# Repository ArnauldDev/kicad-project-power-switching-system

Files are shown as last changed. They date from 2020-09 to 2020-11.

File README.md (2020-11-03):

# Power switching system

Realization of a power supply board with four switches for switching between several power sources.

## Check list

- [x] Analysis of the specifications
- [x] Choice of components and case
- [x] Order components
- [x] Validation of the schematic
- [x] Definition of the PCB outline from the internal dimensions of the case
- [x] Validate component placement and lock footprints
- [x] Routing validation
- [x] Screen printing validation
- [x] Generating design files
- [x] Assembly of components on the PCB
- [x] Functional test of the electronic board and validation of the specifications
- [x] Integration of the electronic card in the case
- [x] Final test and document review
- [ ] Device delivery

---

## Tools used

### KiCad

[KiCad EDA - Schematic Capture & PCB Design Software](https://kicad-pcb.org/), version: 5.1.7

Open source EDA / electronics CAD software for Windows, macOS and Linux.

### FreeCAD - 3D parametric modeler

[FreeCAD](https://www.freecadweb.org/?lang=fr), version: 0.18.4

## Electrical diagram

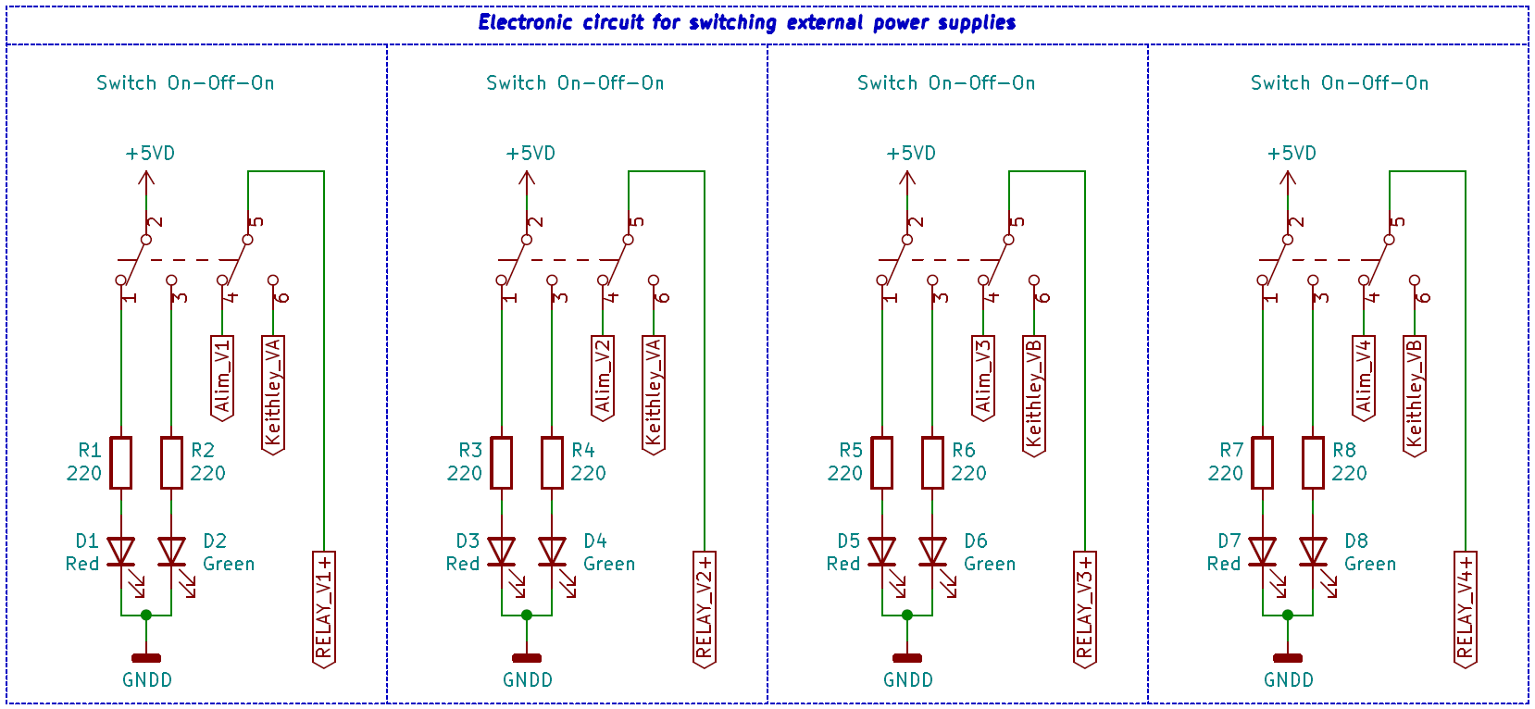
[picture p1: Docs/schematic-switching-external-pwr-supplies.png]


---

## Integration into the housing

[Hammond 1599HGYBAT](https://www.hammfg.com/part/1599HGYBAT)

Enclosure - plastic, size: 220 mm x 110 mm x 44 mm (L x W x H)

## PCB outline, size: 213,00 mm x 96,60 mm (L x W), from FreeCAD

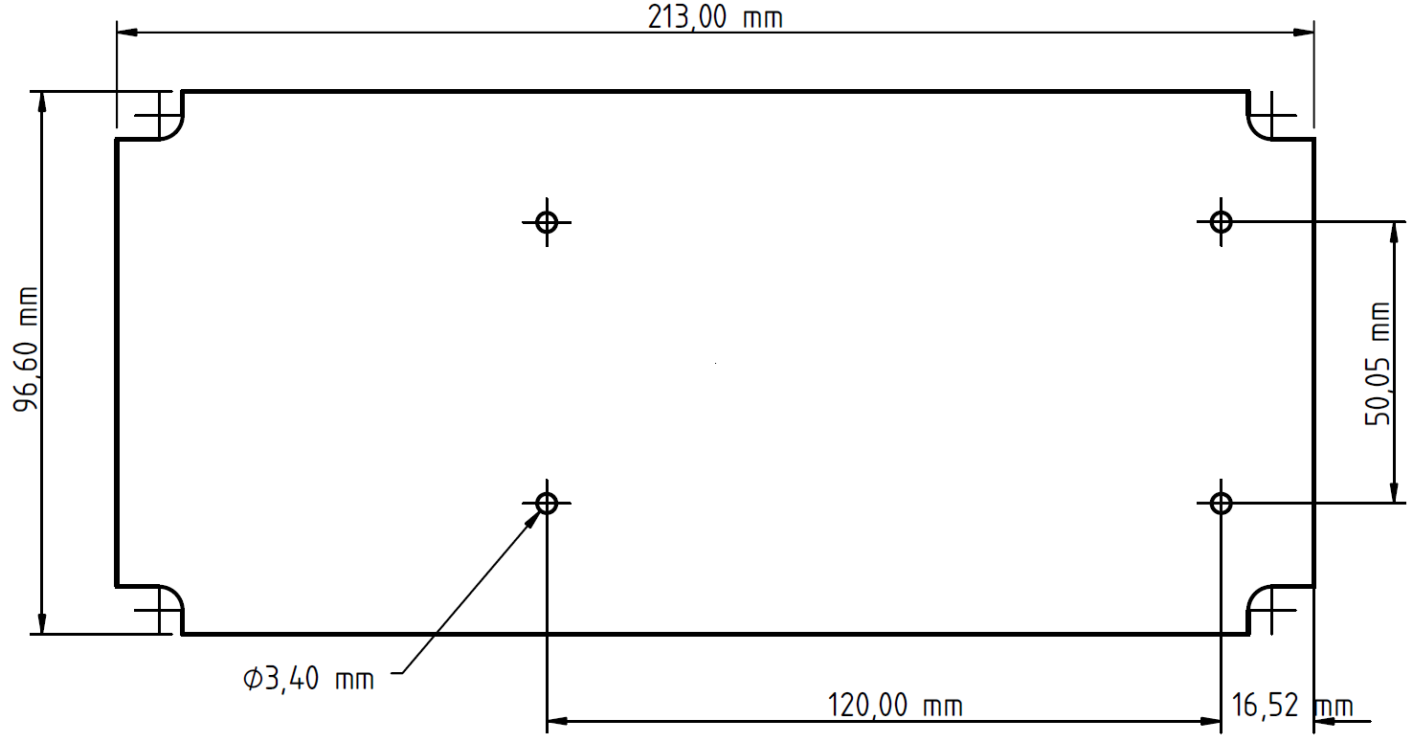
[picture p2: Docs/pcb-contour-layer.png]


## Component placement and silk screen

| Placement | Silk screen |
| :---: | :---: |
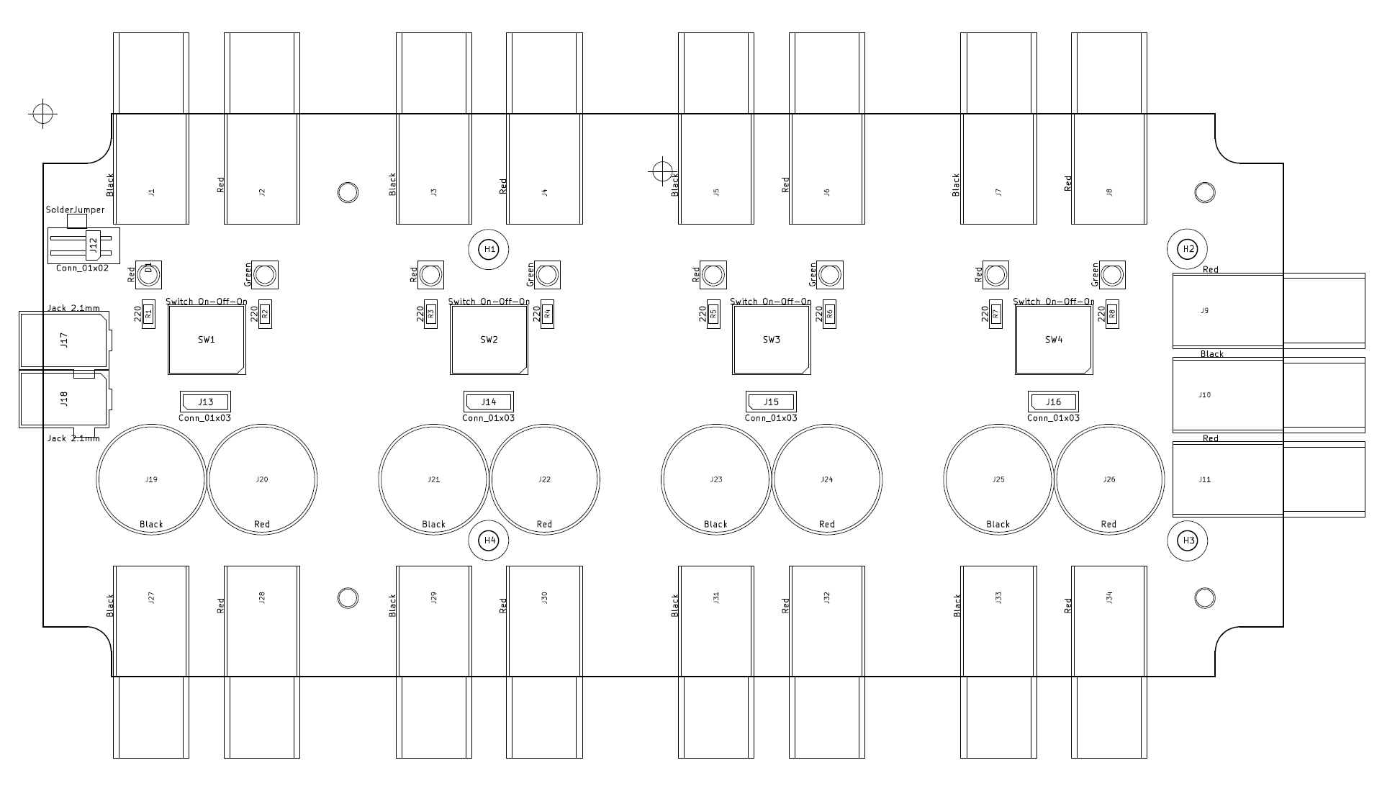
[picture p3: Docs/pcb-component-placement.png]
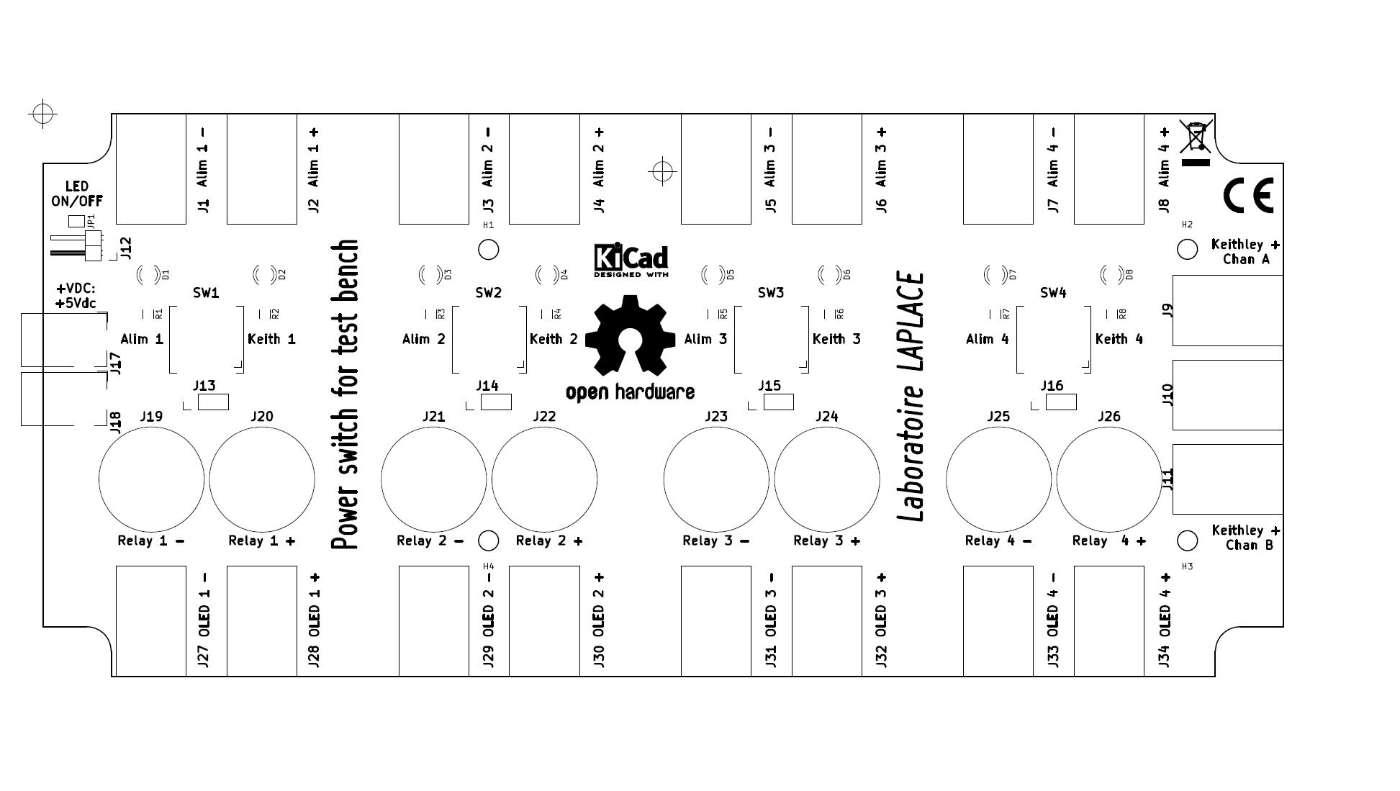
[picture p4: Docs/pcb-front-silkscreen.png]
|  |  |
| F.Mask + Edge.Cuts + F.CrtYd + F.Fab | F.SilkS + Edge.Cuts |

|                      Placement and Silk screen                      |
| :-----------------------------------------------------------------: |
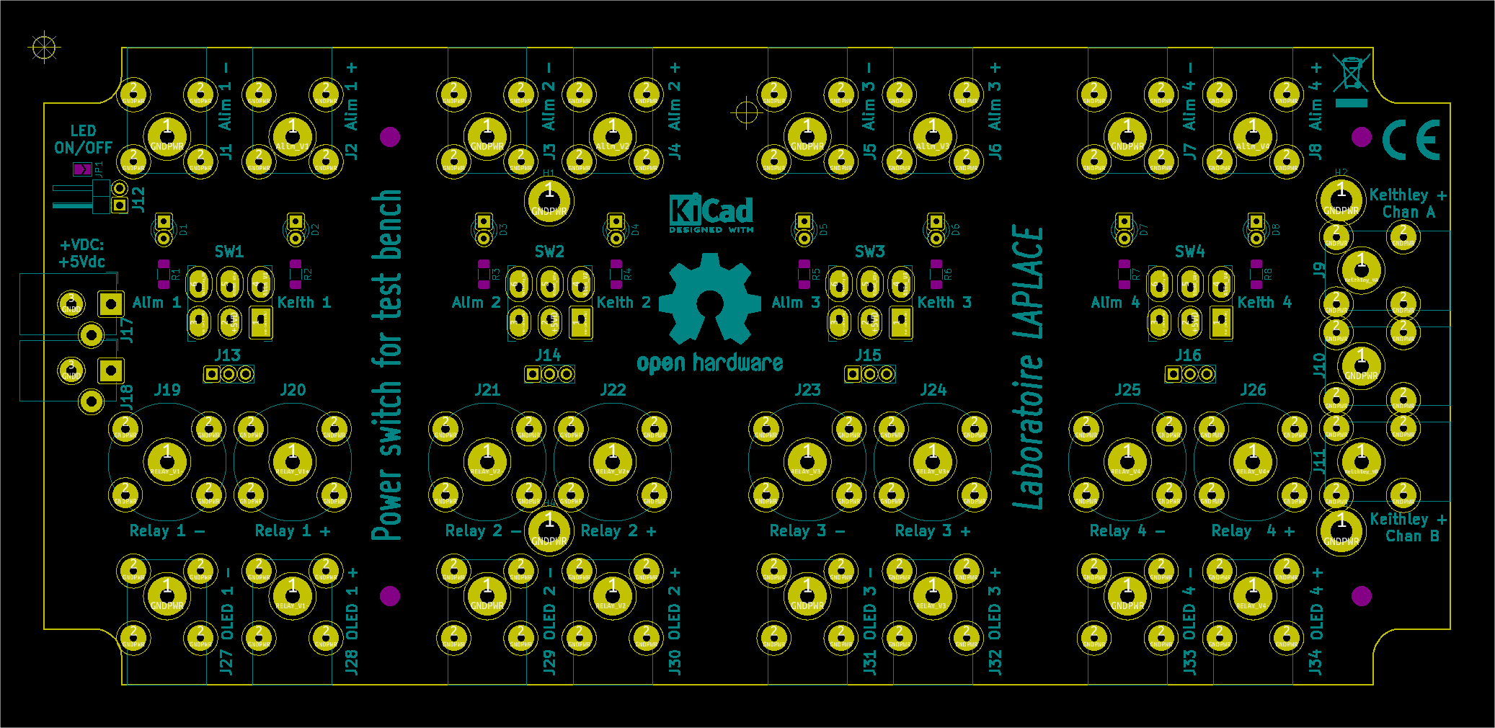
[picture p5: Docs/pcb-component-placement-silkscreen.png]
|  |
|           F.SilkS + F.Mask + Edge.Cuts + F.CrtYd + F.Fab            |

<!--
### Component placement - Component layout

<img src="Docs/pcb-component-placement.png" width="800">

F.Mask + Edge.Cuts + F.CrtYd + F.Fab

### Silk screen

<img src="Docs/pcb-front-silkscreen.png" width="800">

F.SilkS + Edge.Cuts
-->

## Top - Front Copper layer

<!-- ![pcb-front-copper-layer](Docs/pcb-front-copper-layer.png) -->
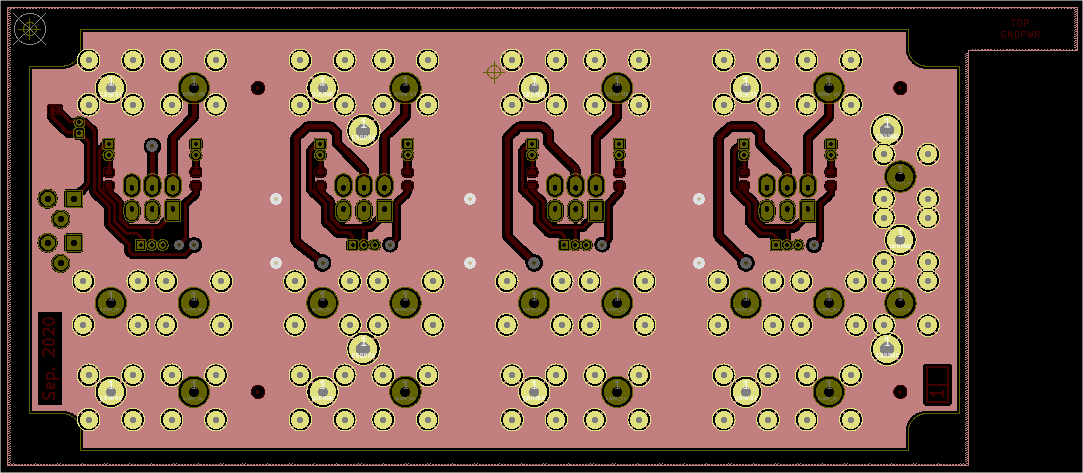
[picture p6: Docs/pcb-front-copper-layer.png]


## Bottom - Back Copper layer

<!-- ![pcb-back-copper-layer](Docs/pcb-back-copper-layer.png) -->
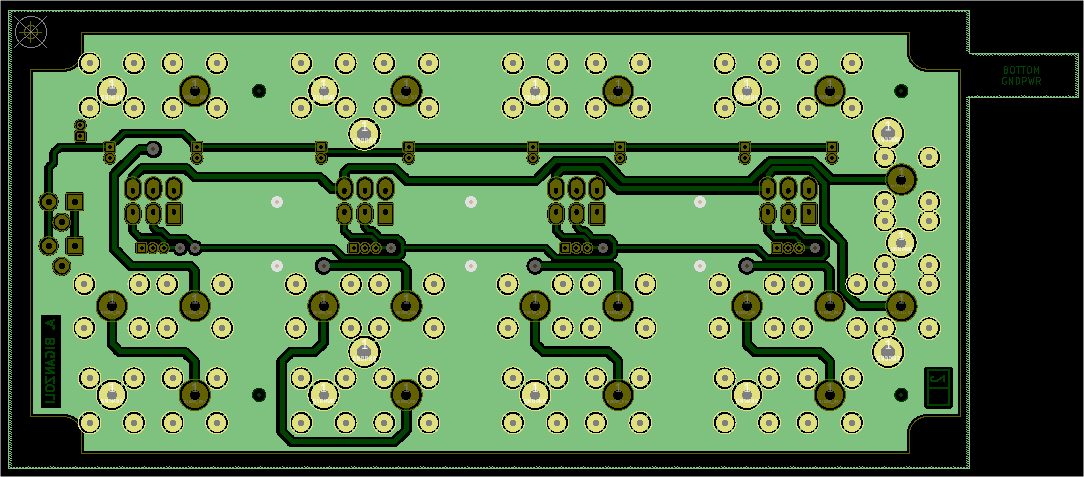
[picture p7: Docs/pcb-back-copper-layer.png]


<!-- ## Component layout

pcb-component-placement.pdf
 -->

## 3D rendering

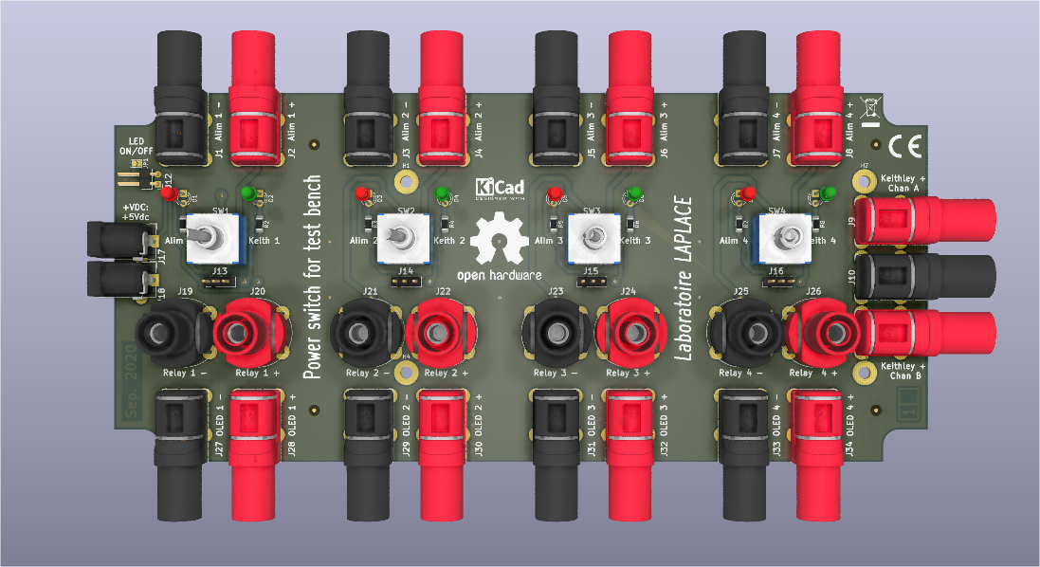
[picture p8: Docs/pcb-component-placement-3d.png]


## Integration of the electronic card in the case with the [FreeCAD](https://www.freecadweb.org) software

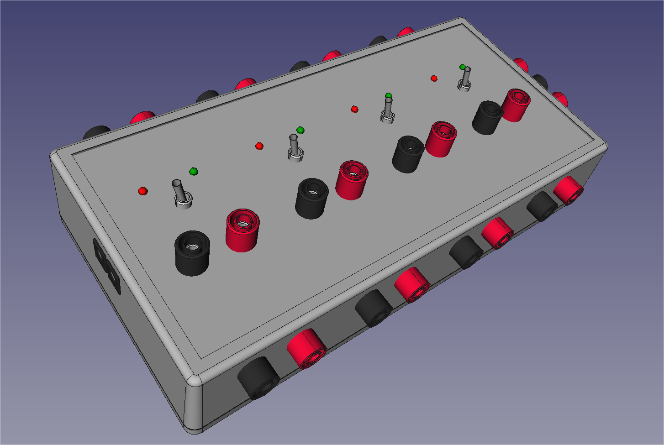
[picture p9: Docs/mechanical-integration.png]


## Sectional view

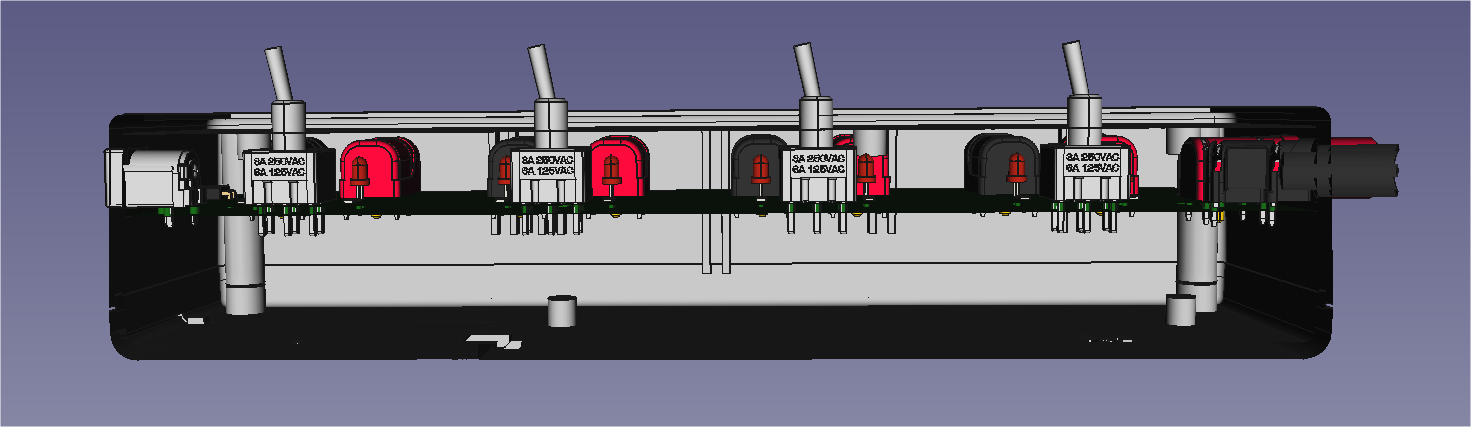
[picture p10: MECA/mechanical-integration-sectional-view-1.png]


## View of final STEP file for CNC

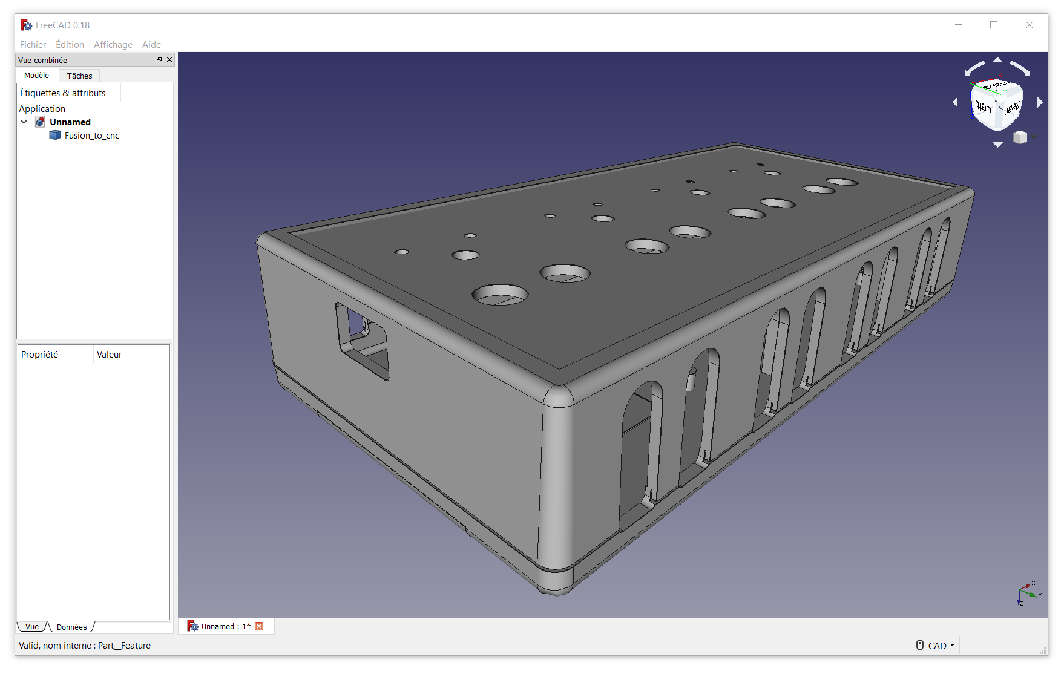
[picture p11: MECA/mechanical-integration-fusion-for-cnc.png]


---

## [CHANGELOG](CHANGELOG.md)

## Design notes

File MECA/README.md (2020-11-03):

# Boîtier Hammond en ABS, 220 x 110 x 44mm, Gris IP54

Code commande RS [514-1897](https://fr.rs-online.com/web/p/boitiers-pour-usage-general/5141897/)

Référence fabricant [1599HGYBAT](https://www.hammfg.com/part/1599HGYBAT)

Marque Hammond

Fixer les LED entre 16 et **18** mm du haut par rapport au plan Top du PCB.

Prévoir colonnette ou entretoise pour réhausser la carte de :

* 18.52 mm depuis l'extrémité supérieur des colonnettes du boitier, diamètre extérieur 5.5 mm
* 23.28 mm du font du boitier au dessous du PCB (for spacer)

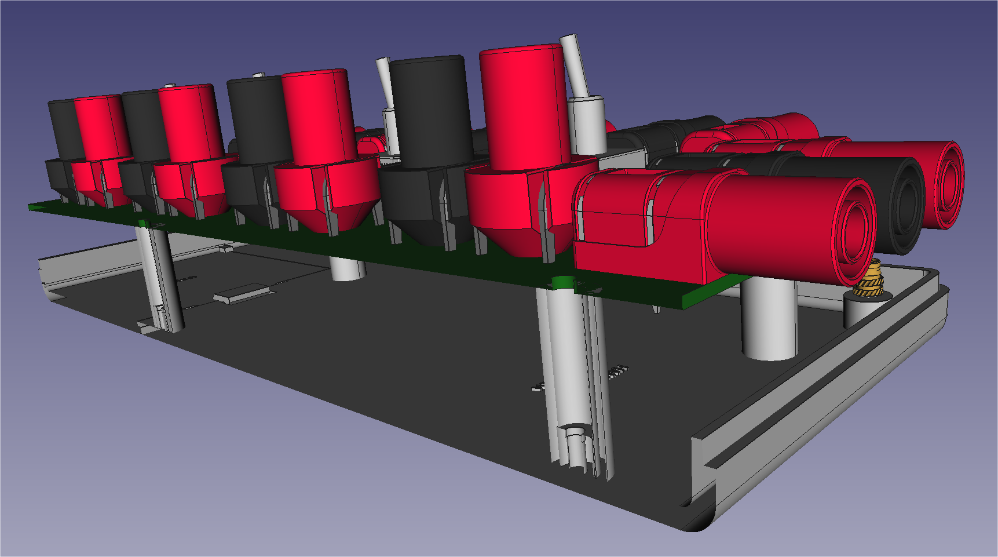
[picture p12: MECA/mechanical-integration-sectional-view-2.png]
Spacer H1:H4


## FreeCAD - 3D parametric modeler

[FreeCAD](https://www.freecadweb.org/?lang=fr), version: 0.18.4

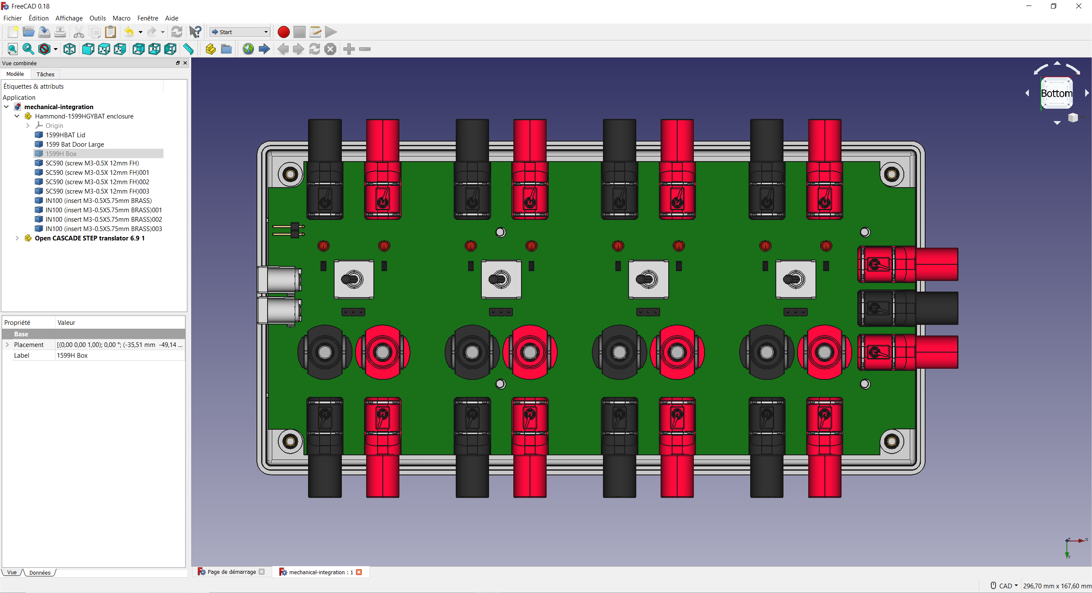
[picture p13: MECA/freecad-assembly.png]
FreeCAD Assembly


## Visualization of the machining of the housing

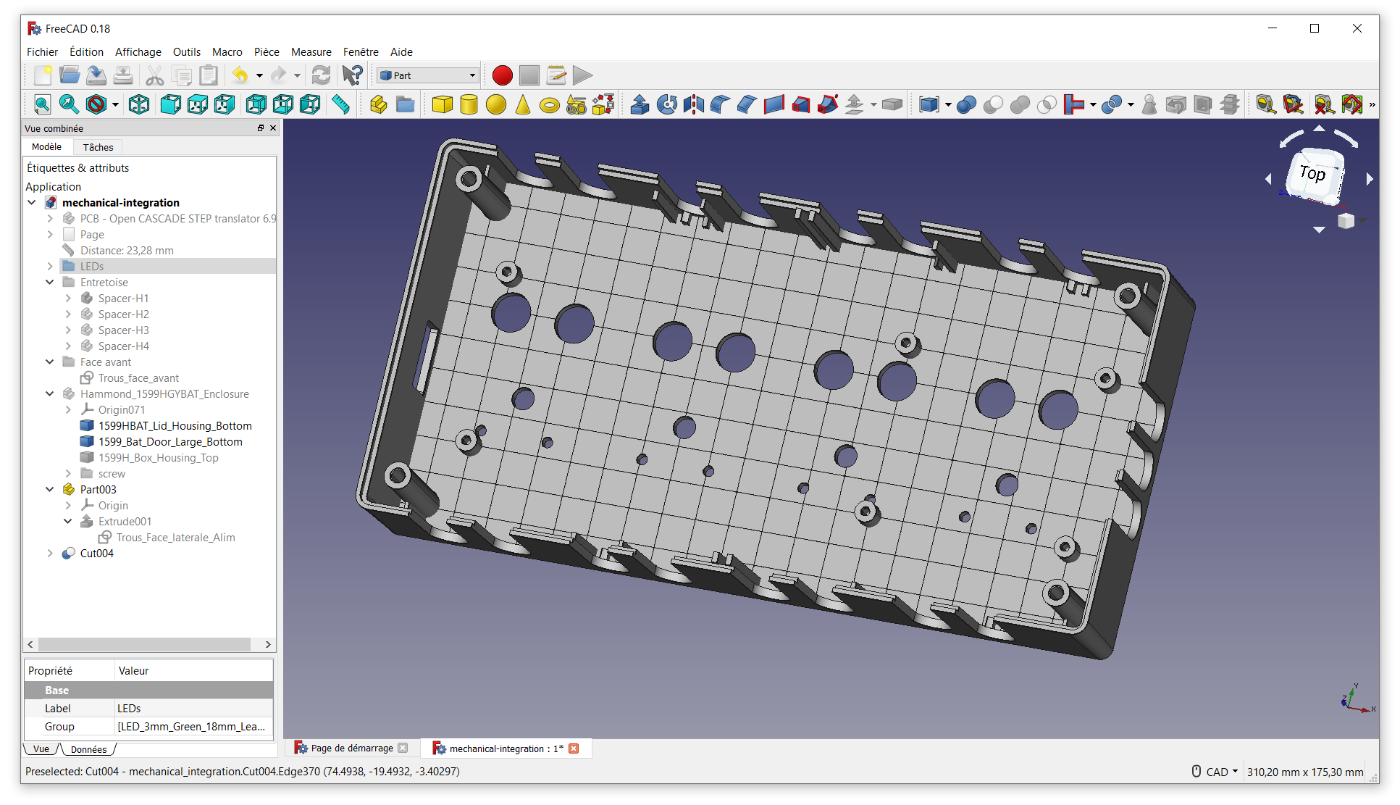
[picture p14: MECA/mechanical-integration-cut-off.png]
Machining of the housing


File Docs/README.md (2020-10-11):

# Project documents

## About the use of KiCad

    Application: KiCad
    Version: (5.1.7)-1, release build
    Libraries:
        wxWidgets 3.0.5
        libcurl/7.71.0 OpenSSL/1.1.1g (Schannel) zlib/1.2.11 brotli/1.0.7 libidn2/2.3.0 libpsl/0.21.0 (+libidn2/2.3.0) libssh2/1.9.0 nghttp2/1.41.0
    Platform: Windows 8 (build 9200), 64-bit edition, 64 bit, Little endian, wxMSW
    Build Info:
        wxWidgets: 3.0.5 (wchar_t,wx containers,compatible with 2.8)
        Boost: 1.73.0
        OpenCASCADE Community Edition: 6.9.1
        Curl: 7.71.0
        Compiler: GCC 10.2.0 with C++ ABI 1014

    Build settings:

        KICAD_SCRIPTING_WXPYTHON=ON
        KICAD_SCRIPTING_WXPYTHON_PHOENIX=OFF
        KICAD_SCRIPTING_ACTION_MENU=ON
        BUILD_GITHUB_PLUGIN=ON
        KICAD_USE_OCE=ON
        KICAD_USE_OCC=OFF
        KICAD_SPICE=ON

### Local library

    .
    └── kicad-project-power-switching-system
        ├── kicad_local_lib
        └── kicad_local_mod
            └── Button_Switch_THT.pretty (Local_Button_Switch_THT)
            └── Connector_Banana.pretty (Local_Connector_Banana)
            └── Connector_BarrelJack.pretty (Local_Connector_BarrelJack)
            └── Layer_ID.pretty
            └── LED_THT.pretty
            └── packages3d
                └── Button_Switch_THT.3dshapes
                └── Connector_Banana.3dshapes
                └── Connector_BarrelJack.3dshapes
                └── LED_THT.3dshapes

### Library management in KiCad version 5

[KiCad Library Convention](https://kicad-pcb.org/libraries/klc/)

### Additional fields in Symbol Properties

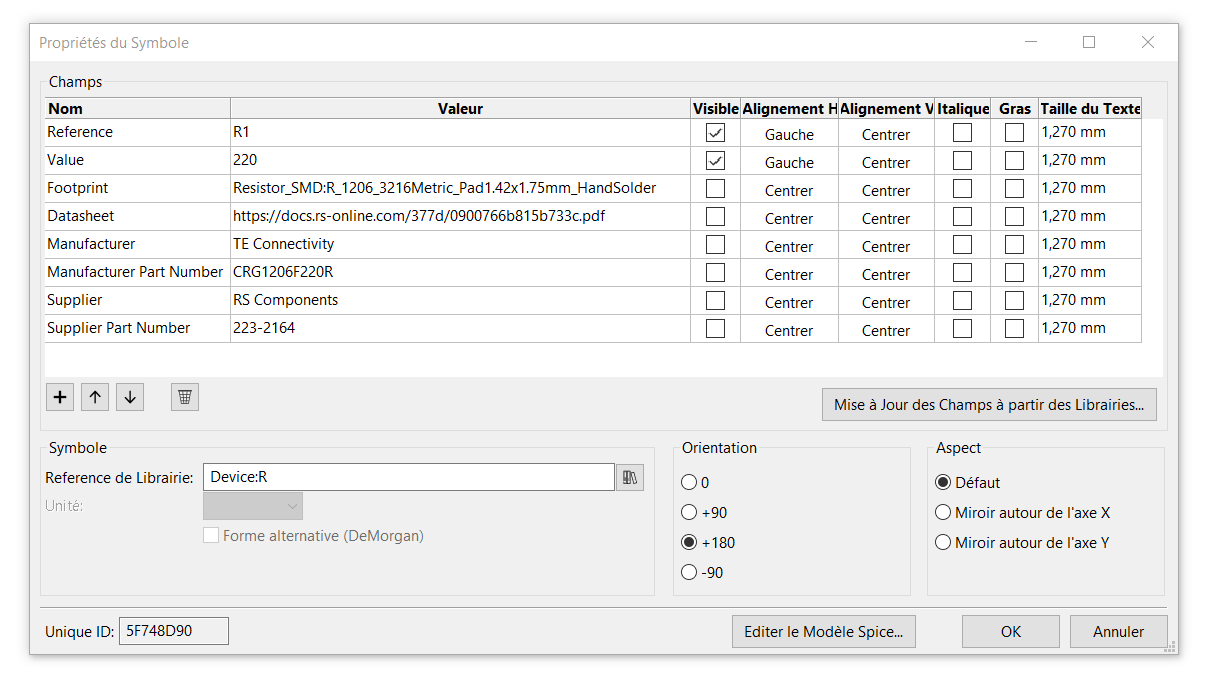
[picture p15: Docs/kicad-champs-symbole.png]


---

## About the use of FreeCAD

https://www.freecadweb.org/downloads.php

    OS: Windows 10
    Word size of OS: 64-bit
    Word size of FreeCAD: 64-bit
    Version: 0.18.4 (GitTag)
    Build type: Release
    Branch: releases/FreeCAD-0-18
    Hash: 980bf9060e28555fecd9e3462f68ca74007b70f8
    Python version: 3.6.6
    Qt version: 5.6.2
    Coin version: 4.0.0a
    OCC version: 7.3.0
    Locale: French/France (fr_FR)

---

## Open Source Hardware Association

<!-- ![oshw-logo](oshw-logo-200-px.png) -->
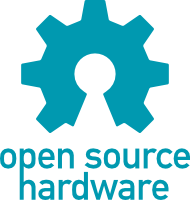
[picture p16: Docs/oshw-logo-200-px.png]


https://www.oshwa.org/

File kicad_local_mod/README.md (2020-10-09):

# kicad-local_mod

Project footprint

## Change lists

### SW_TME_1MD3T1B1M1QE_DPDT_Straight.kicad_mod

Edit inter footprint

oblong hole : 0.9 x 1.3 mm

--> 1.0 x 1.4 mm

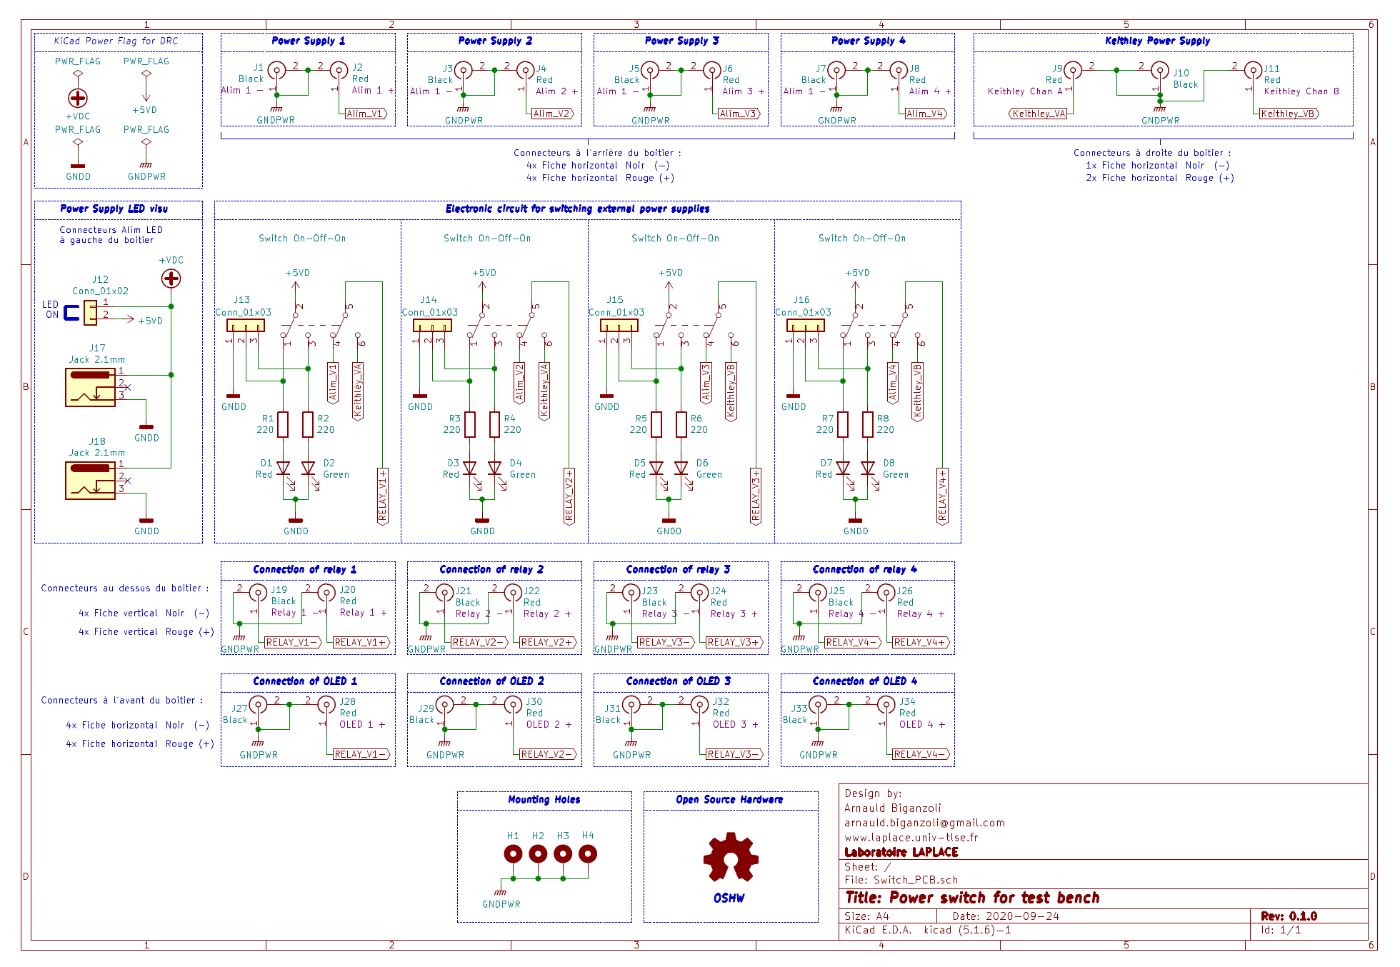
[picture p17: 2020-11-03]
Docs/schematic-switch-alim-v0-1-0.png

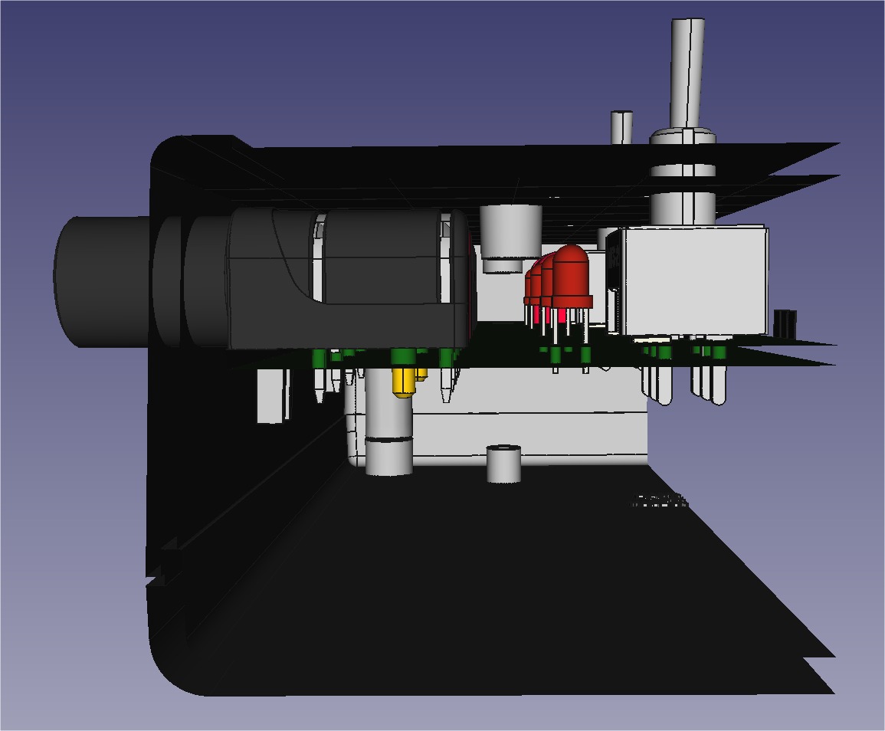
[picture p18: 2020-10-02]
MECA/mechanical-integration-sectional-view-3.png

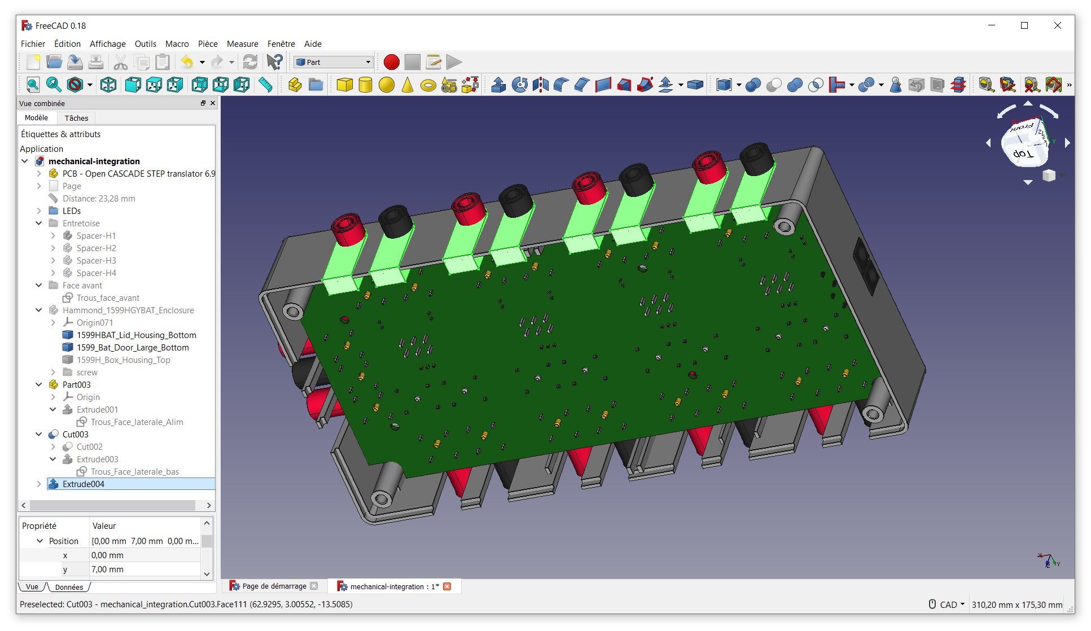
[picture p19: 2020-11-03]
MECA/mechanical-integration-add-part-for-subtraction.png

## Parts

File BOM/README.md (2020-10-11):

# Bill Of Materials (BOM), public prices as of september 2020

 | Description                                                                     | Supplier         | Supplier Part Number    | Quantity | By multiple of    | Unit price | Row value |
 | :------------------------------------------------------------------------------ | :--------------- | :---------------------: | :------: | ----------------- | ---------: | --------: |
 | Boîtier Hammond en ABS, 220 x 110 x 44mm, Gris IP54                             | RS Components    | [514-1897][url_5141897] |    1     | unit              |    12,16 € |   12,16 € |
 | Alimentation enfichable 5V c.c., 1A, 5W                                         | RS Components    | [121-7115][url_1217115] |    1     | unit              |     6,67 € |    6,67 € |
 | Connecteur Jack RS PRO Double c.c. Femelle 2,1 mm, 2,5 mm, Montage sur CI       | RS Components    | [805-1699][url_8051699] |    2     | in multiples of 5 |    1,282 € |    6,41 € |
 | Alimentation enfichable 5V c.c., 1A, 5W                                         | RS Components    | [121-7115][url_1217115] |    1     | unit              |    6,003 € |    6,00 € |
 | LED Rouge, Traversant, 3 mm (T-1), 2 V                                          | RS Components    | [228-5916][url_2285916] |    4     | in multiples of 5 |    0,126 € |    0,63 € |
 | LED Vert, Traversant, 3 mm (T-1), 2,2 V                                         | RS Components    | [228-5944][url_2285944] |    4     | in multiples of 5 |    0,126 € |    0,63 € |
 | Fiche banane Staubli Noir Femelle 24A 1 kV, 600 V (vertical)                    | RS Components    | [122-9670][url_1229670] |    4     | unit              |    6,138 € |  24,552 € |
 | Fiche banane Staubli Rouge Femelle 24A 1 kV, 600 V (vertical)                   | RS Components    | [122-9671][url_1229671] |    4     | unit              |    6,138 € |  24,552 € |
 | Fiche banane Schutzinger Noir Embase 24A 1kV (horizontal)                       | RS Components    | [144-1451][url_1441451] |    9     | unit              |    5,238 € |  47,142 € |
 | Fiche banane Schutzinger Rouge Embase 24A 1kV (horizontal)                      | RS Components    | [144-1450][url_1441450] |    10    | unit              |    5,238 € |    52,4 € |
 | Interrupteur à levier RS PRO, On-Off-On, 2RT, 5 A @ 28 V c.c.                   | RS Components    | [401-692][url_0401692]  |    4     | unit              |    2,484 € |   9,936 € |
 | _______________________________________________________________________________ | ________________ | _______________________ | ________ | _________________ | __________ | _________ |
 |                                                                                 |                  |                         |          |                   |      TOTAL |  191,08 € |

[url_5141897]: https://fr.rs-online.com/web/p/boitiers-pour-usage-general/5141897
[url_1217115]: https://fr.rs-online.com/web/p/adaptateurs-ac-dc/1217115/
[url_8051699]: https://fr.rs-online.com/web/p/fiches-et-prises-jack/8051699/
[url_1217115]: https://fr.rs-online.com/web/p/adaptateurs-ac-dc/1217115/
[url_2285916]: https://fr.rs-online.com/web/p/led/2285916/
[url_2285944]: https://fr.rs-online.com/web/p/led/2285944/
[url_1229670]: https://fr.rs-online.com/web/p/fiches-bananes/1229670/
[url_1229671]: https://fr.rs-online.com/web/p/fiches-bananes/1229671/
[url_1441451]: https://fr.rs-online.com/web/p/fiches-bananes/1441451/
[url_1441450]: https://fr.rs-online.com/web/p/fiches-bananes/1441450/
[url_0401692]: https://fr.rs-online.com/web/p/interrupteurs-a-levier/0401692/

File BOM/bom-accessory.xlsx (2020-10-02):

Reference | Quantity | Value | Footprint | Datasheet | Description | Manufacturer | Manufacturer Part Number | Supplier | Supplier Part Number
 | 1 |  |  |  | Boîtier Hammond en ABS, 220 x 110 x 44mm, Gris IP54 | Hammond | 1599HGYBAT | RS Components | 514-1897

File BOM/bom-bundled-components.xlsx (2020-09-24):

Reference | Quantity | Value | Footprint | Datasheet | Description | Manufacturer | Manufacturer Part Number | Supplier | Supplier Part Number
D1 D7 D5 D3 | 4 | Red | LED_THT:LED_D3.0mm | https://docs.rs-online.com/5919/0900766b813955e6.pdf | LED Alim 1 | Kingbright | L-934ID | RS Components | 228-5916
D8 D6 D4 D2 | 4 | Green | LED_THT:LED_D3.0mm | https://docs.rs-online.com/c1ec/0900766b813955e9.pdf | LED Keith VB2 | Kingbright | L-934GD | RS Components | 228-5944
H1 H2 H3 H4 | 4 | MountingHole_Pad | MountingHole:MountingHole_3.2mm_M3_Pad | ~
J10 J7 J5 J3 J1 J21 J23 J25 J27 | 9 | Black | ArnauldDev_Connector_Banana:SCHUTZINGER_SWEB8094AU-SW_4mm_Horizontal | https://www.schuetzinger.de/files/sweb_8094_au_110520.pdf | GND | Schutzinger | SWEB 8094 Au / SW | RS Components | 144-1451
J12-1 J12-2 | 2 | Jack 2.1mm | ArnauldDev_Connector_BarrelJack:BarrelJack_FC681465P_Pin3_Horizontal | https://www.cliffuk.co.uk/products/dcconnectors/FC681465P.pdf | Alim 5 Vdc | CLIFF | FC681465P (DC-10LP) | RS Components | 805-1699
J13 J15 J17 J19 | 4 | Black | ArnauldDev_Connector_Banana:STAUBLI_66.9032-21_XELA-4_4mm_Vertical | https://ec.staubli.com/AcroFiles/MA/TM_MAH565_(de-en-fr).pdf | Relay 1 - | Staubli | 66.9032-21 | RS Components | 122-9670
J14 J16 J18 J20 | 4 | Red | ArnauldDev_Connector_Banana:STAUBLI_66.9032-21_XELA-4_4mm_Vertical | https://ec.staubli.com/AcroFiles/MA/TM_MAH565_(de-en-fr).pdf | Relay 1 + | Staubli | 66.9032-22 | RS Components | 122-9671
J4 J9 J6 J8 J11 J2 J26 J22 J28 J24 | 10 | Red | ArnauldDev_Connector_Banana:SCHUTZINGER_SWEB8094AU-SW_4mm_Horizontal | https://www.schuetzinger.de/files/sweb_8094_au_110520.pdf | Alim 2 + | Schutzinger | SWEB 8094 Au / RT | RS Components | 144-1450
R8 R7 R6 R5 R4 R3 R2 R1 | 8 | 220 | Resistor_SMD:R_1206_3216Metric_Pad1.42x1.75mm_HandSolder | https://docs.rs-online.com/377d/0900766b815b733c.pdf |  | TE Connectivity | CRG1206F220R | RS Components | 223-2164
SW3 SW4 SW2 SW1 | 4 | Switch On-Off-On | ArnauldDev_Button_Switch_THT:SW_TME_1MD3T1B1M1QE_DPDT_Straight | https://datasheet.octopart.com/401692-RS-Pro-datasheet-110811736.pdf | Switch of Alim 3 | RS PRO / TME | 1MD3T1B1M1QE | RS Components | 401-692

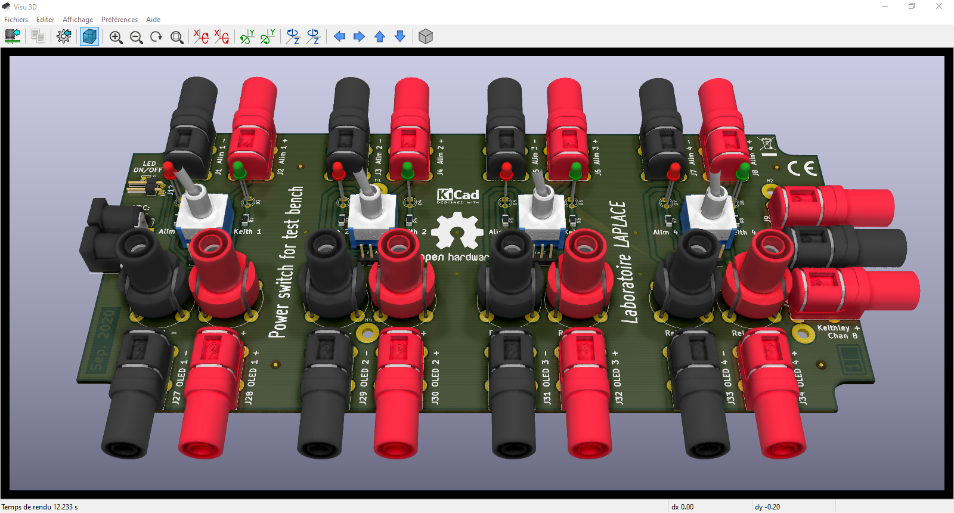
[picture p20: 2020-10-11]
Docs/pcb-component-placement-3d-inc.png

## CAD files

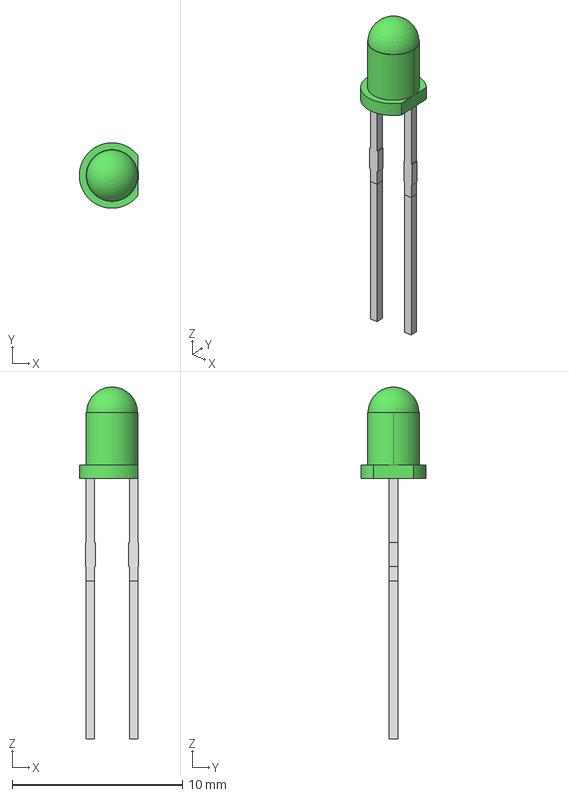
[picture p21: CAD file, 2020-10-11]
MECA/led/led-3mm-green-h18mm.FCStd
3.50 x 3.85 x 20.7 mm
LEDBody
Lead1Body
Lead2Body
LEDHead
Lead1Pcb
Lead2Pcb

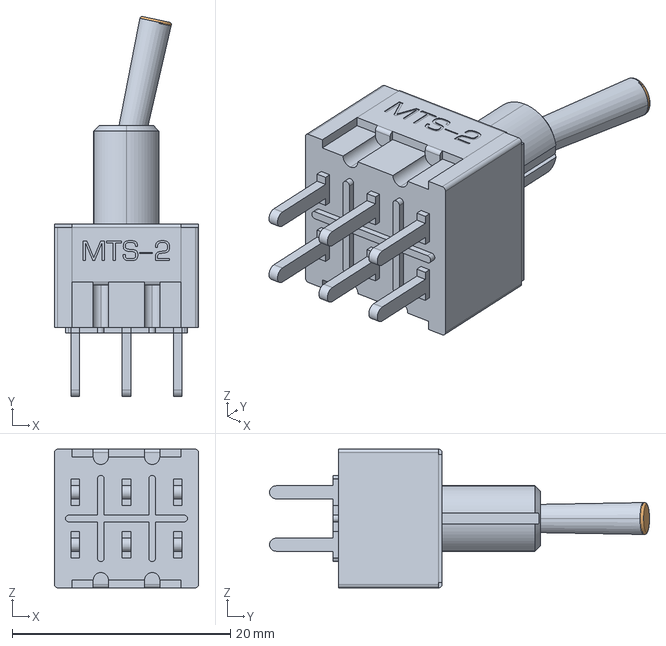
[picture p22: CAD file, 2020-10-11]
MECA/SW_TME_1MD3T1B1M1QE_DPDT_Straight.FCStd
13.2 x 34.8 x 12.7 mm
User Library-MTS-20x-A2

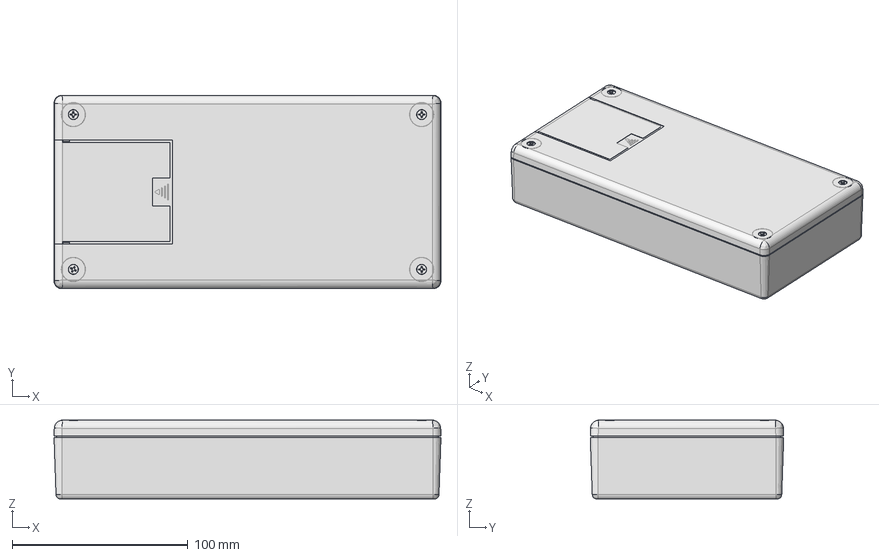
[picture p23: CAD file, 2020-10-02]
MECA/Hammond-1599HGYBAT.step
220.0 x 110.0 x 44.9 mm
1599H Lid
1599 Bat Door Large
1599H Box
SC500 (screw M3-0.5X 10mm FH) x 4
Insert x 4

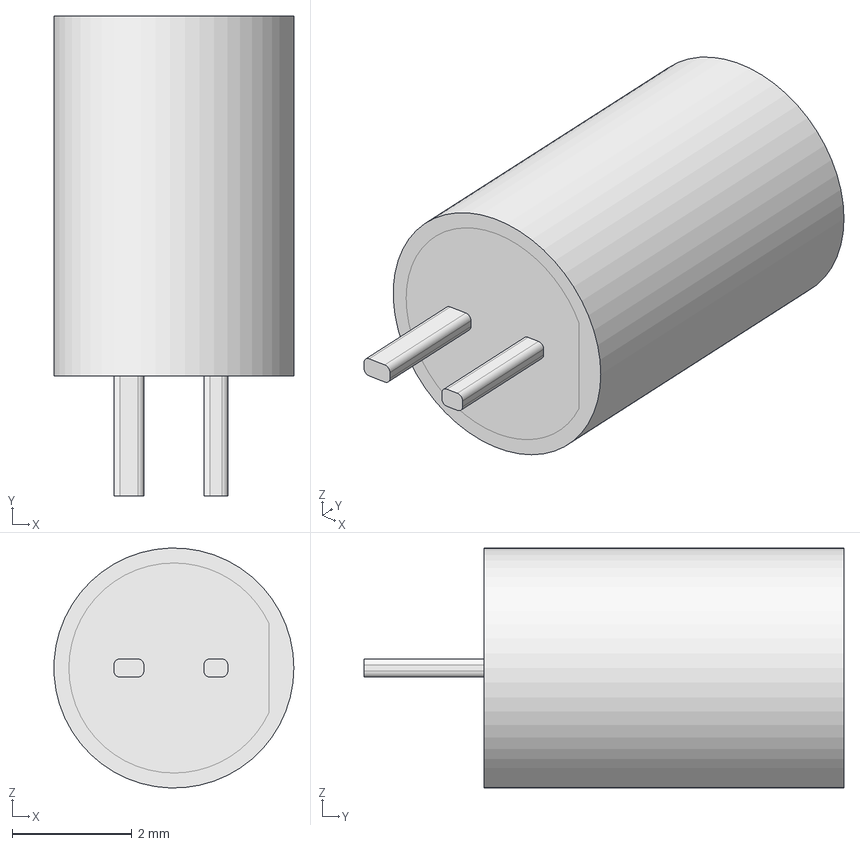
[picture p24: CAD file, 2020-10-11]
MECA/led/led-3mm-green.FCStd
4.00 x 8.00 x 4.00 mm

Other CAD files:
MECA/led/led-3mm-red-h18mm.FCStd
MECA/led/LED_D3.0mm_H18.0mm_Red.step
MECA/led/LED_D3.0mm_H18.0mm_Green.step

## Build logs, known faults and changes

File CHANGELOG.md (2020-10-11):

## 0.1.1 - 2020-10-11

> kicad_local_mod\Connector_Banana.pretty\SCHUTZINGER_SWEB8094AU-RT_4mm_Horizontal_Red.kicad_mod

* Change reference position of an object in FreeCAD, so that it is correctly placed in KiCad

## 0.1.0 - 2020-10-10

* Added: insert layers number on pcb

## 0.0.9 - 2020-10-09

* Fixed: missing fiduciale

## 0.0.8 - 2020-10-07

* Update local inter footprint SW_TME_1MD3T1B1M1QE_DPDT_Straight.kicad_mod, change for oblong hole.

## 0.0.7 - 2020-10-07

* Create local components library

## 0.0.6 - 2020-10-02

* Project review and mechanical integration

## 0.0.5 - 2020-10-01

* Added: via on GNDPWR

## 0.0.4 - 2020-09-30

* Routing completed

## 0.0.3 - 2020-09-28

* Added: 3 pin connector for LED states

## 0.0.2 - 2020-09-26

* Update color for each Banana connector to the pcb component placement 3d rendered.

## 0.0.1 - 2020-09-24

✨ First release

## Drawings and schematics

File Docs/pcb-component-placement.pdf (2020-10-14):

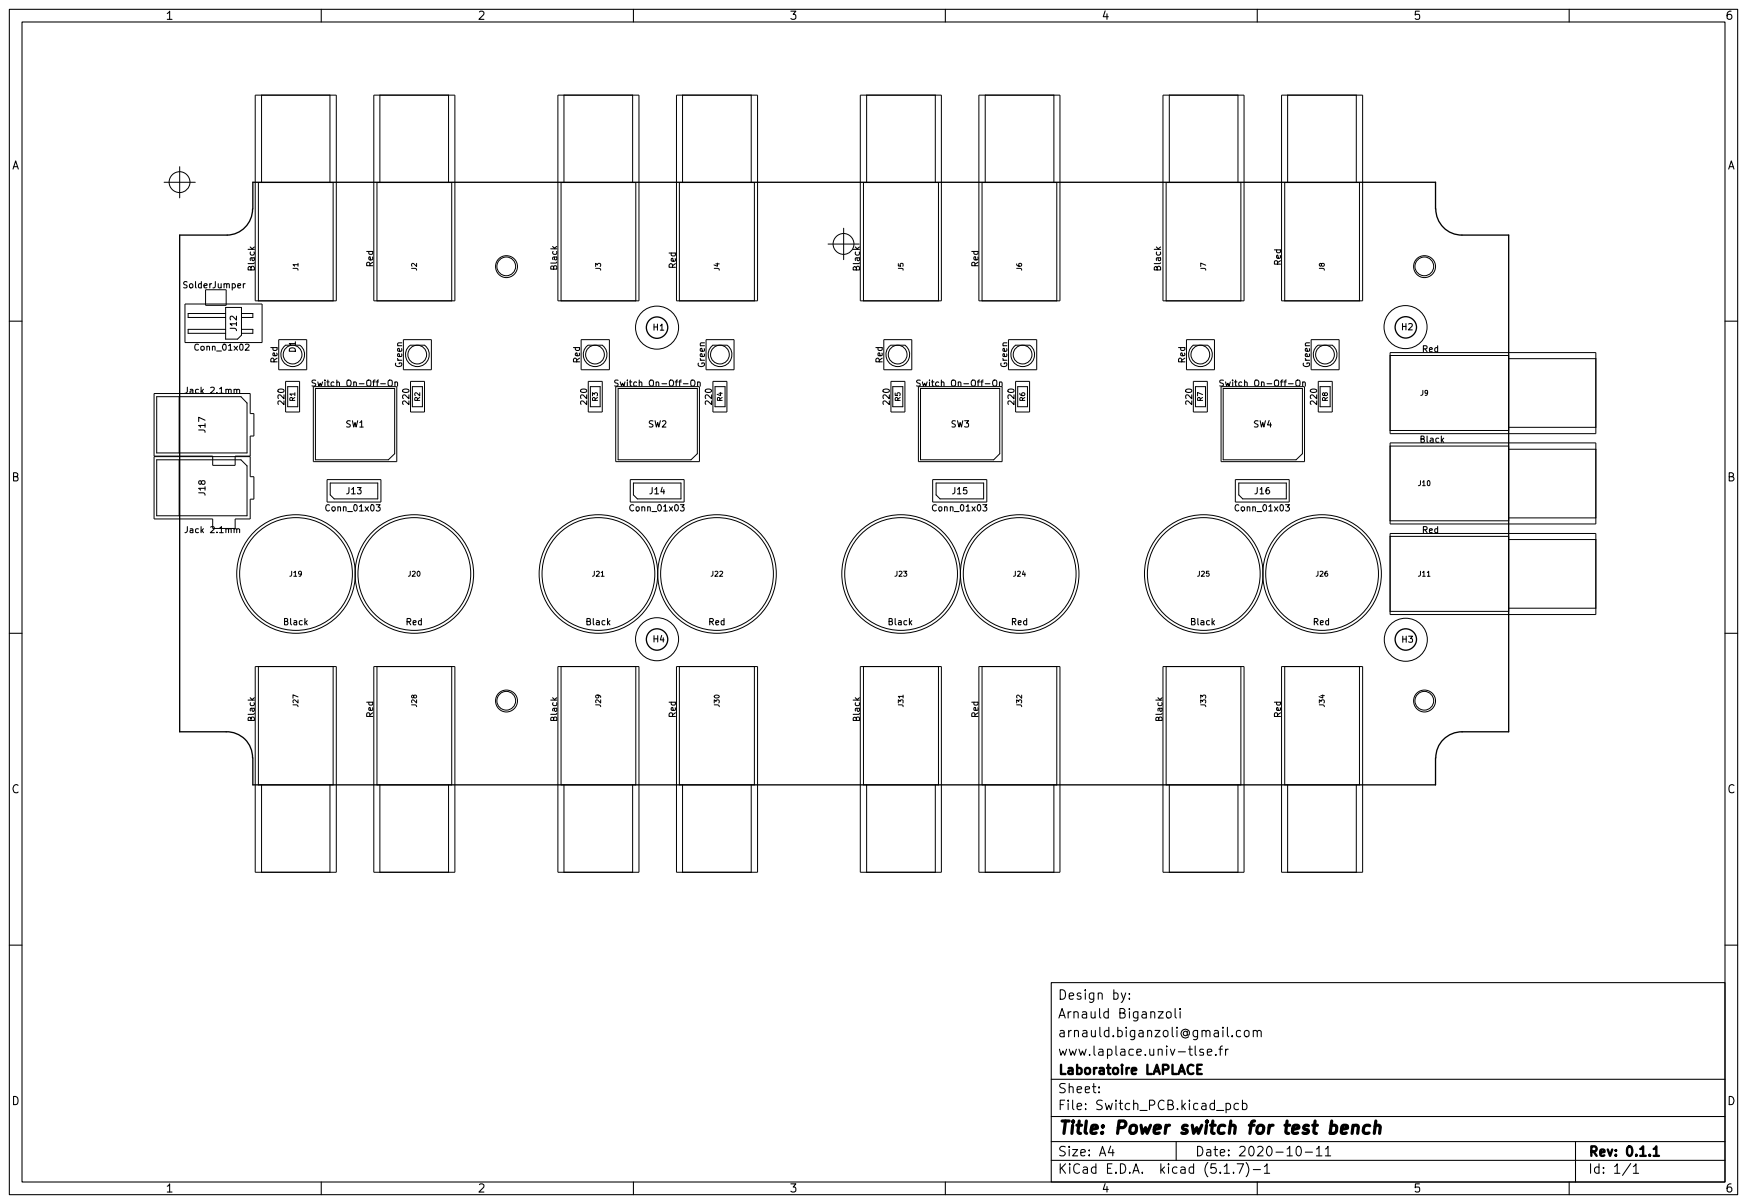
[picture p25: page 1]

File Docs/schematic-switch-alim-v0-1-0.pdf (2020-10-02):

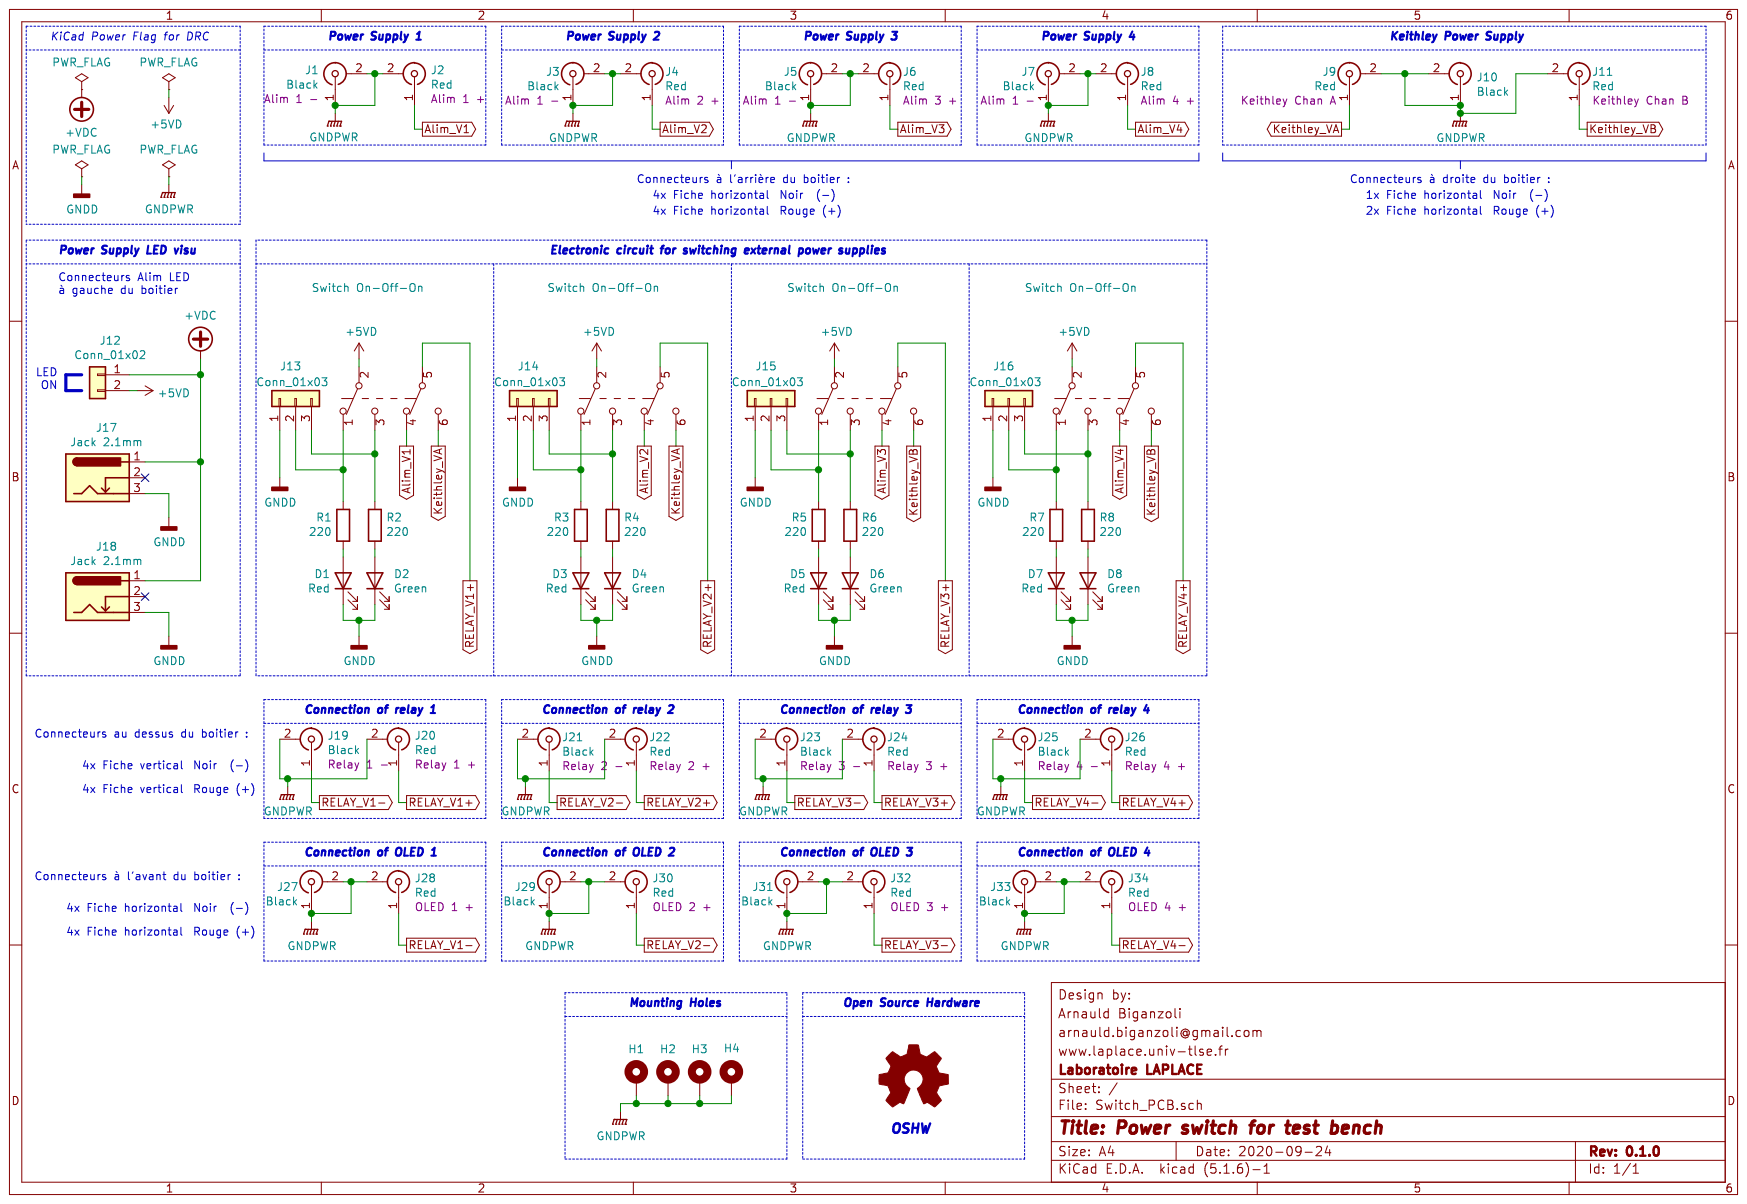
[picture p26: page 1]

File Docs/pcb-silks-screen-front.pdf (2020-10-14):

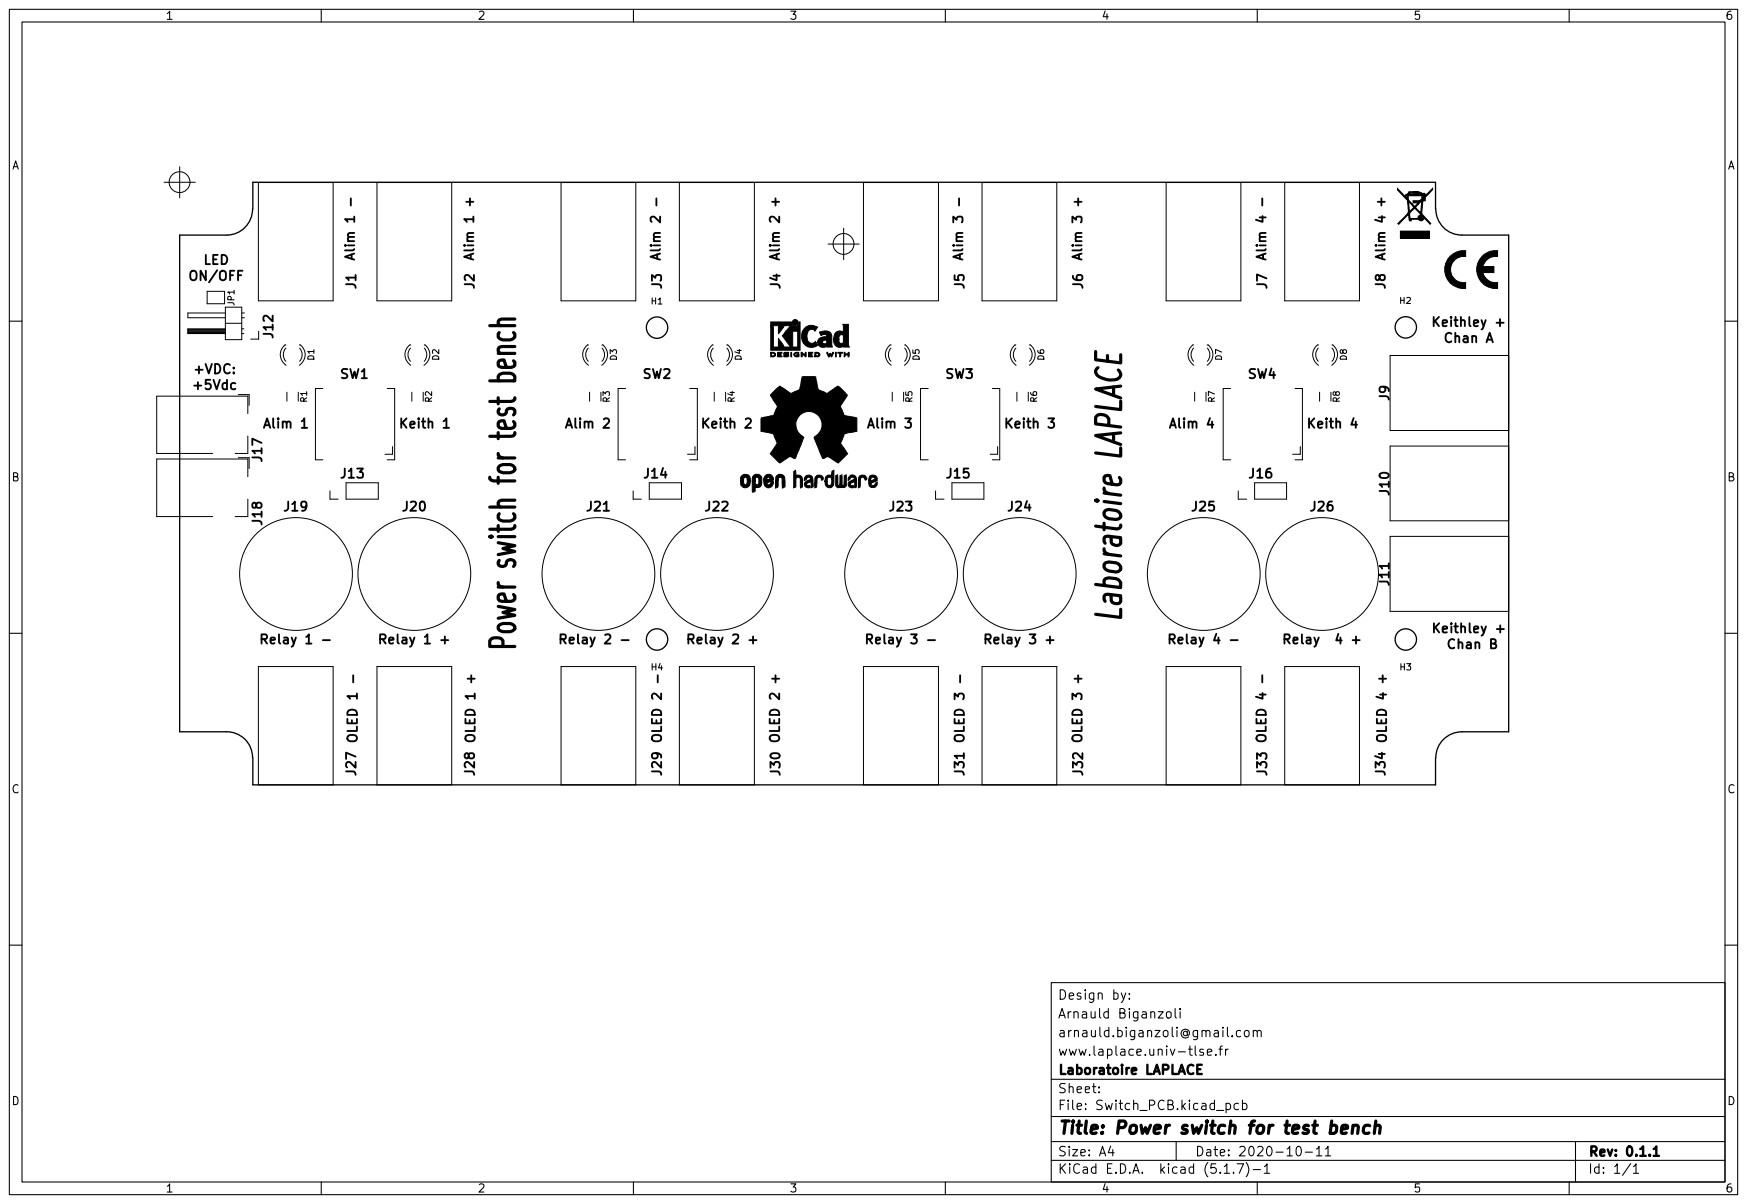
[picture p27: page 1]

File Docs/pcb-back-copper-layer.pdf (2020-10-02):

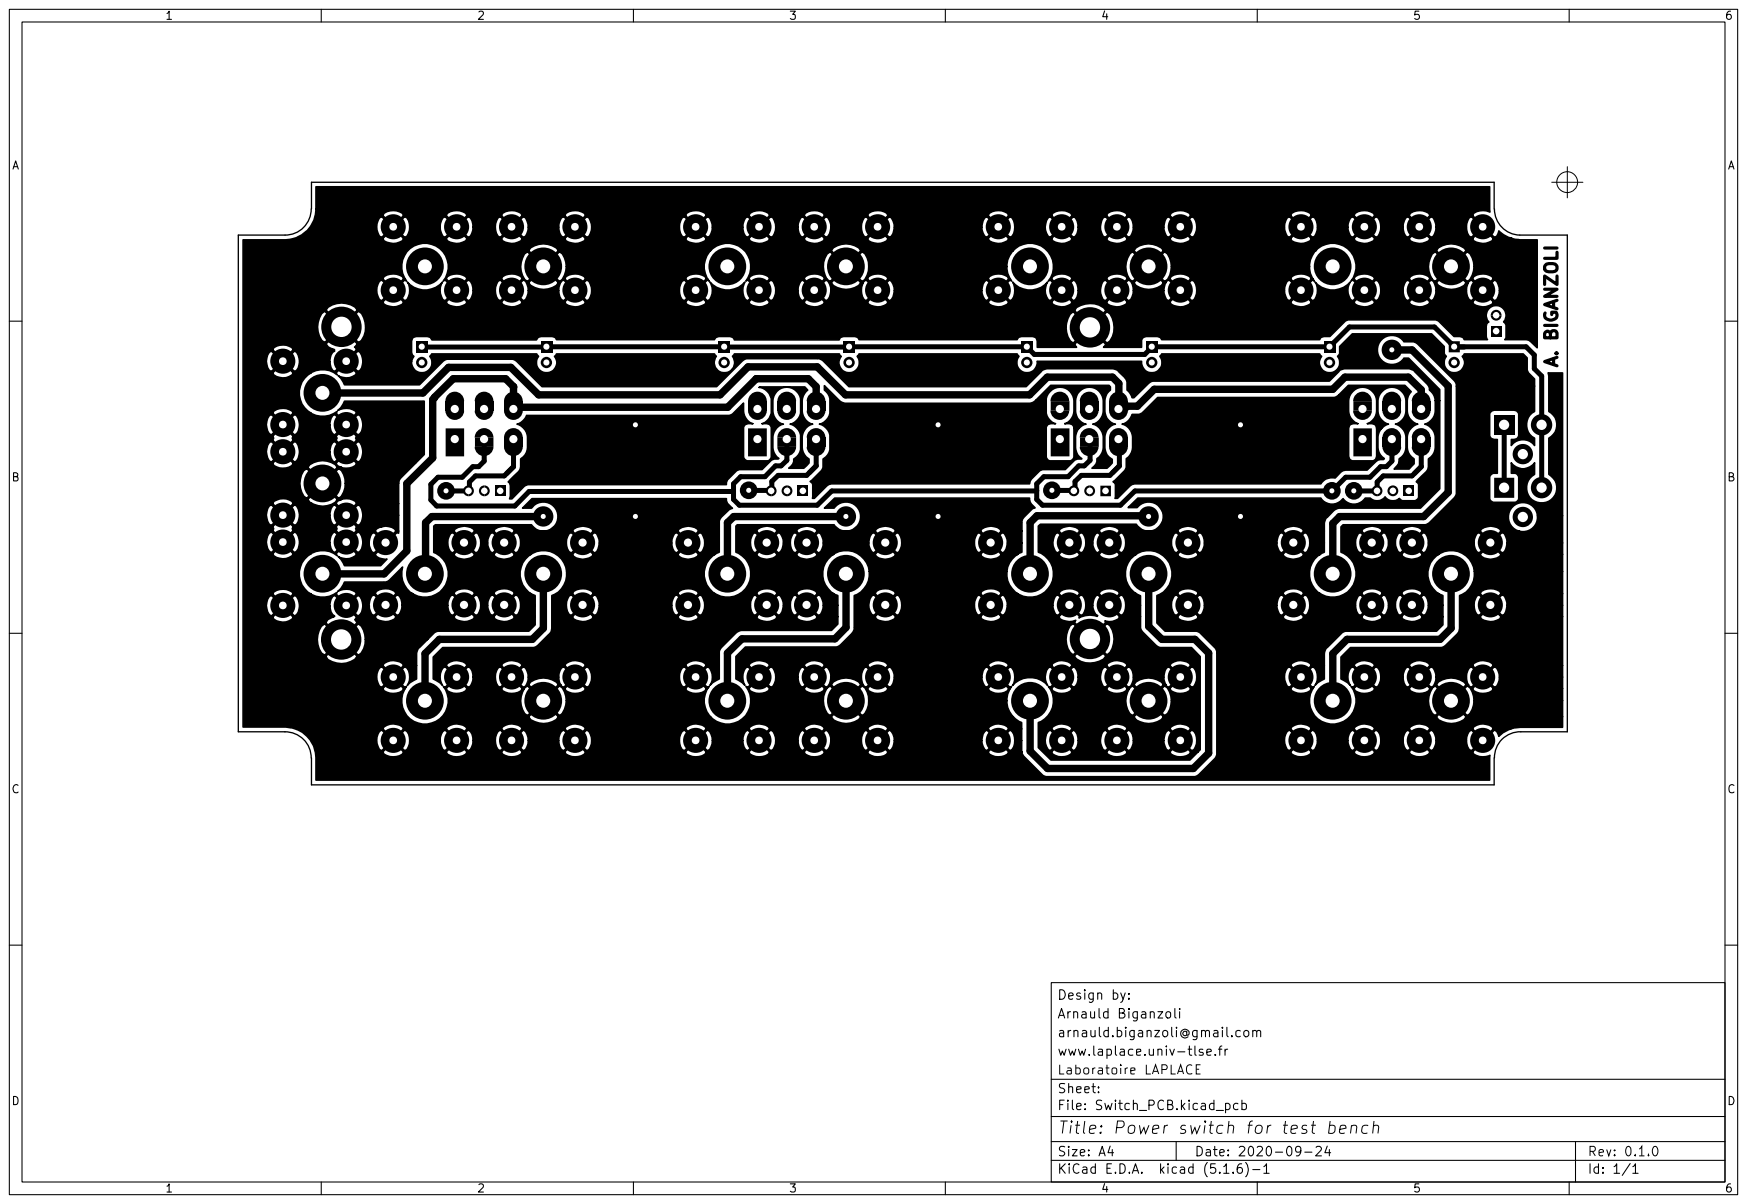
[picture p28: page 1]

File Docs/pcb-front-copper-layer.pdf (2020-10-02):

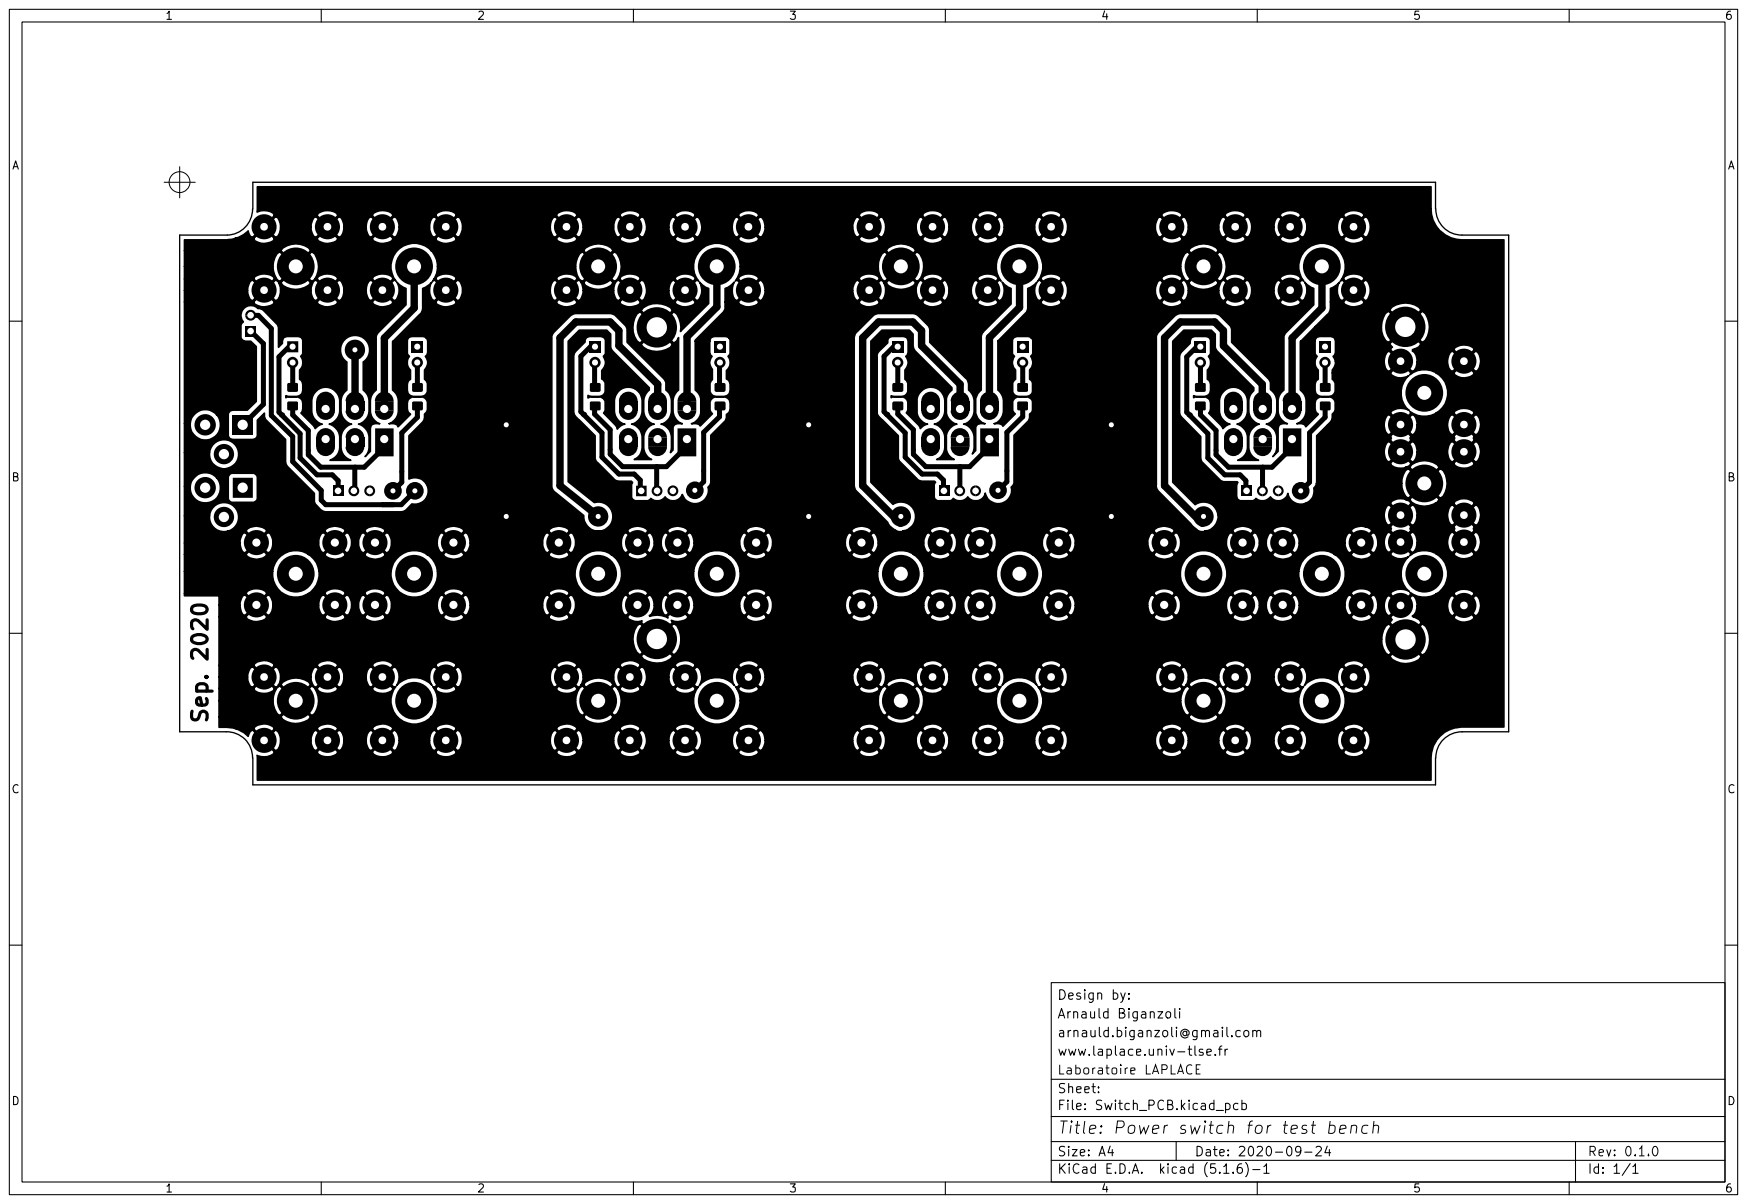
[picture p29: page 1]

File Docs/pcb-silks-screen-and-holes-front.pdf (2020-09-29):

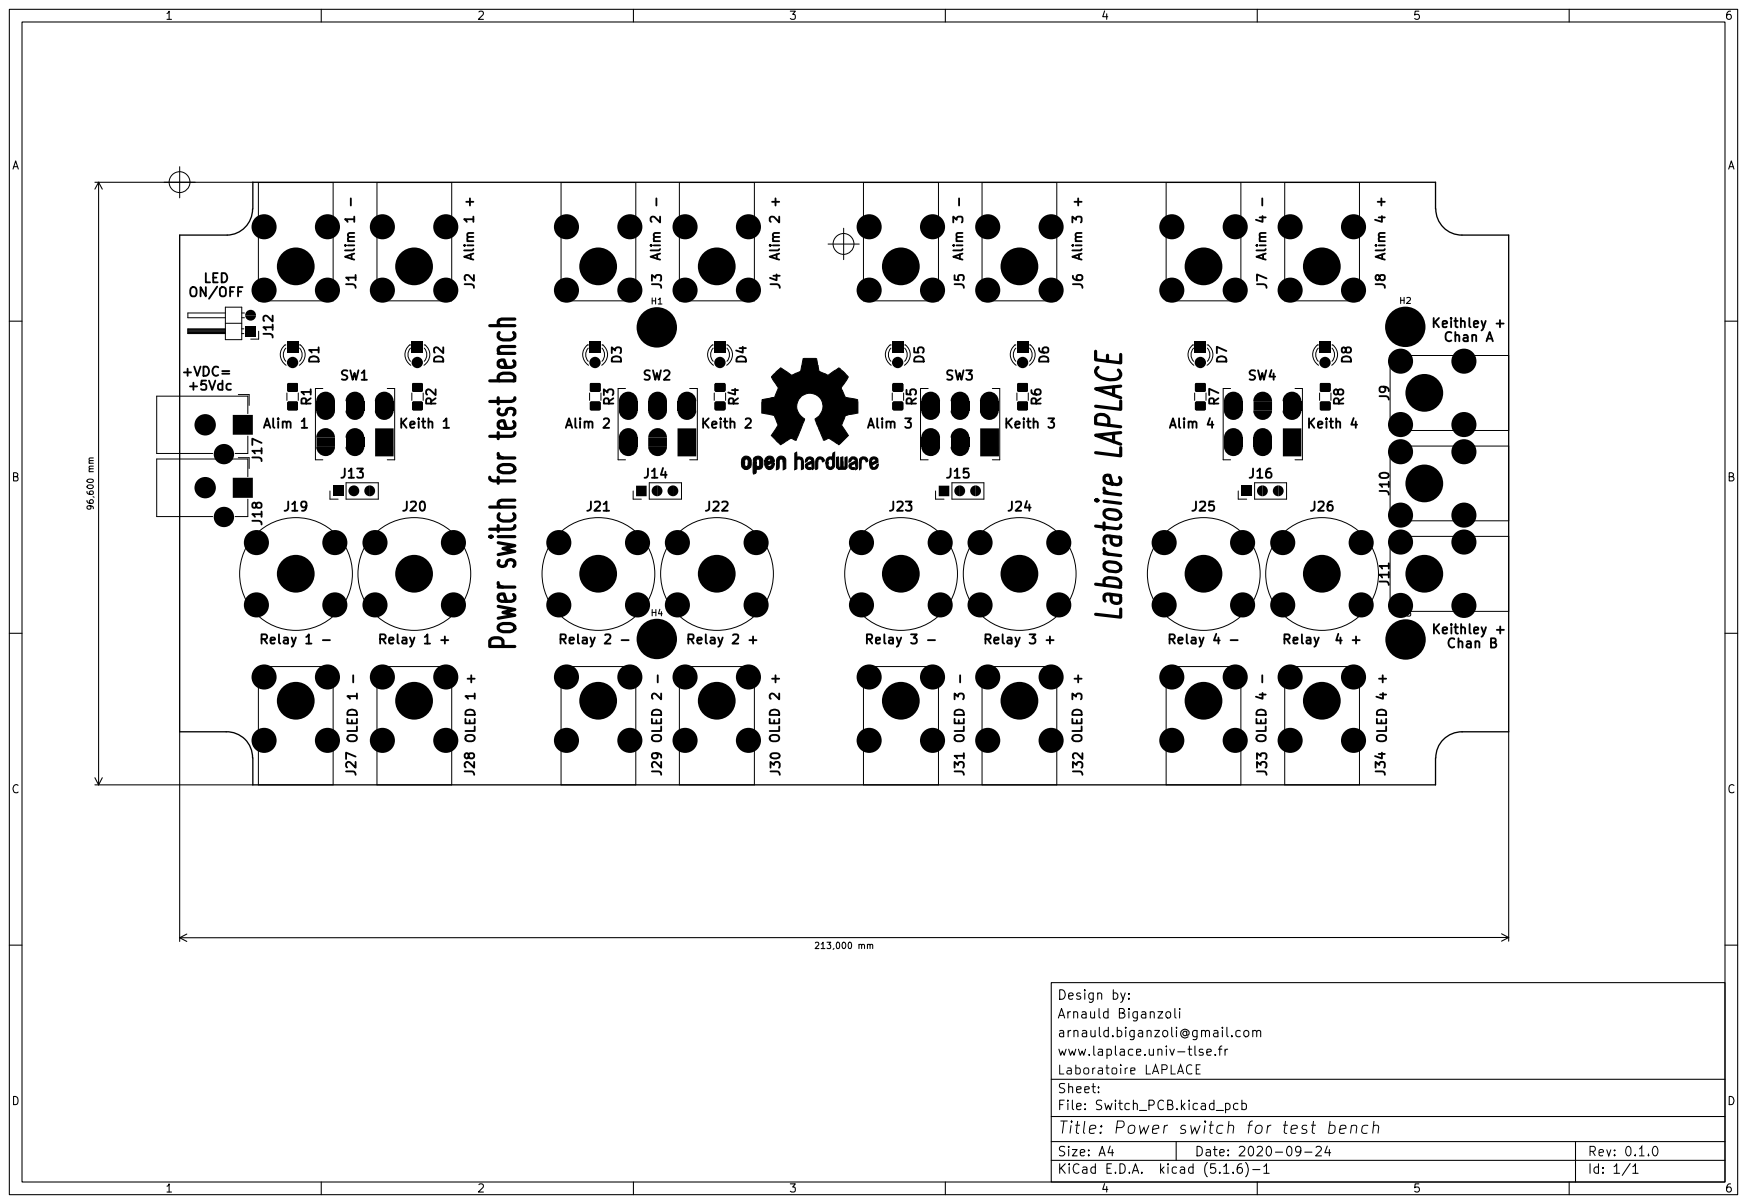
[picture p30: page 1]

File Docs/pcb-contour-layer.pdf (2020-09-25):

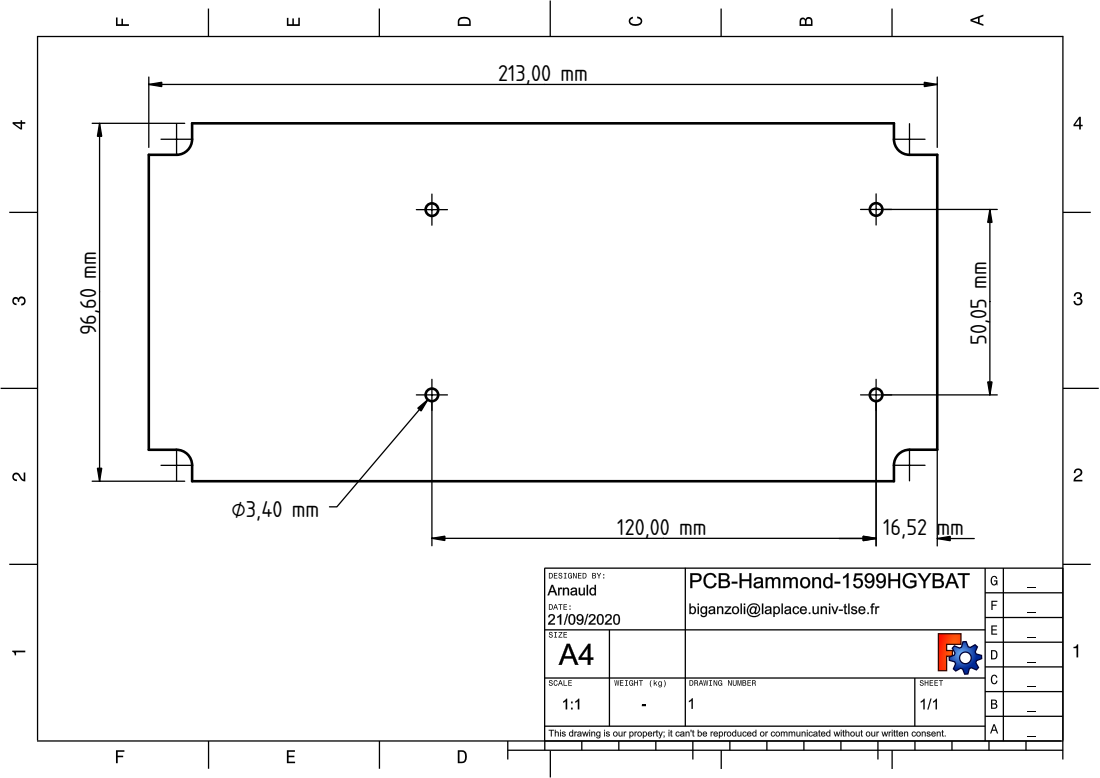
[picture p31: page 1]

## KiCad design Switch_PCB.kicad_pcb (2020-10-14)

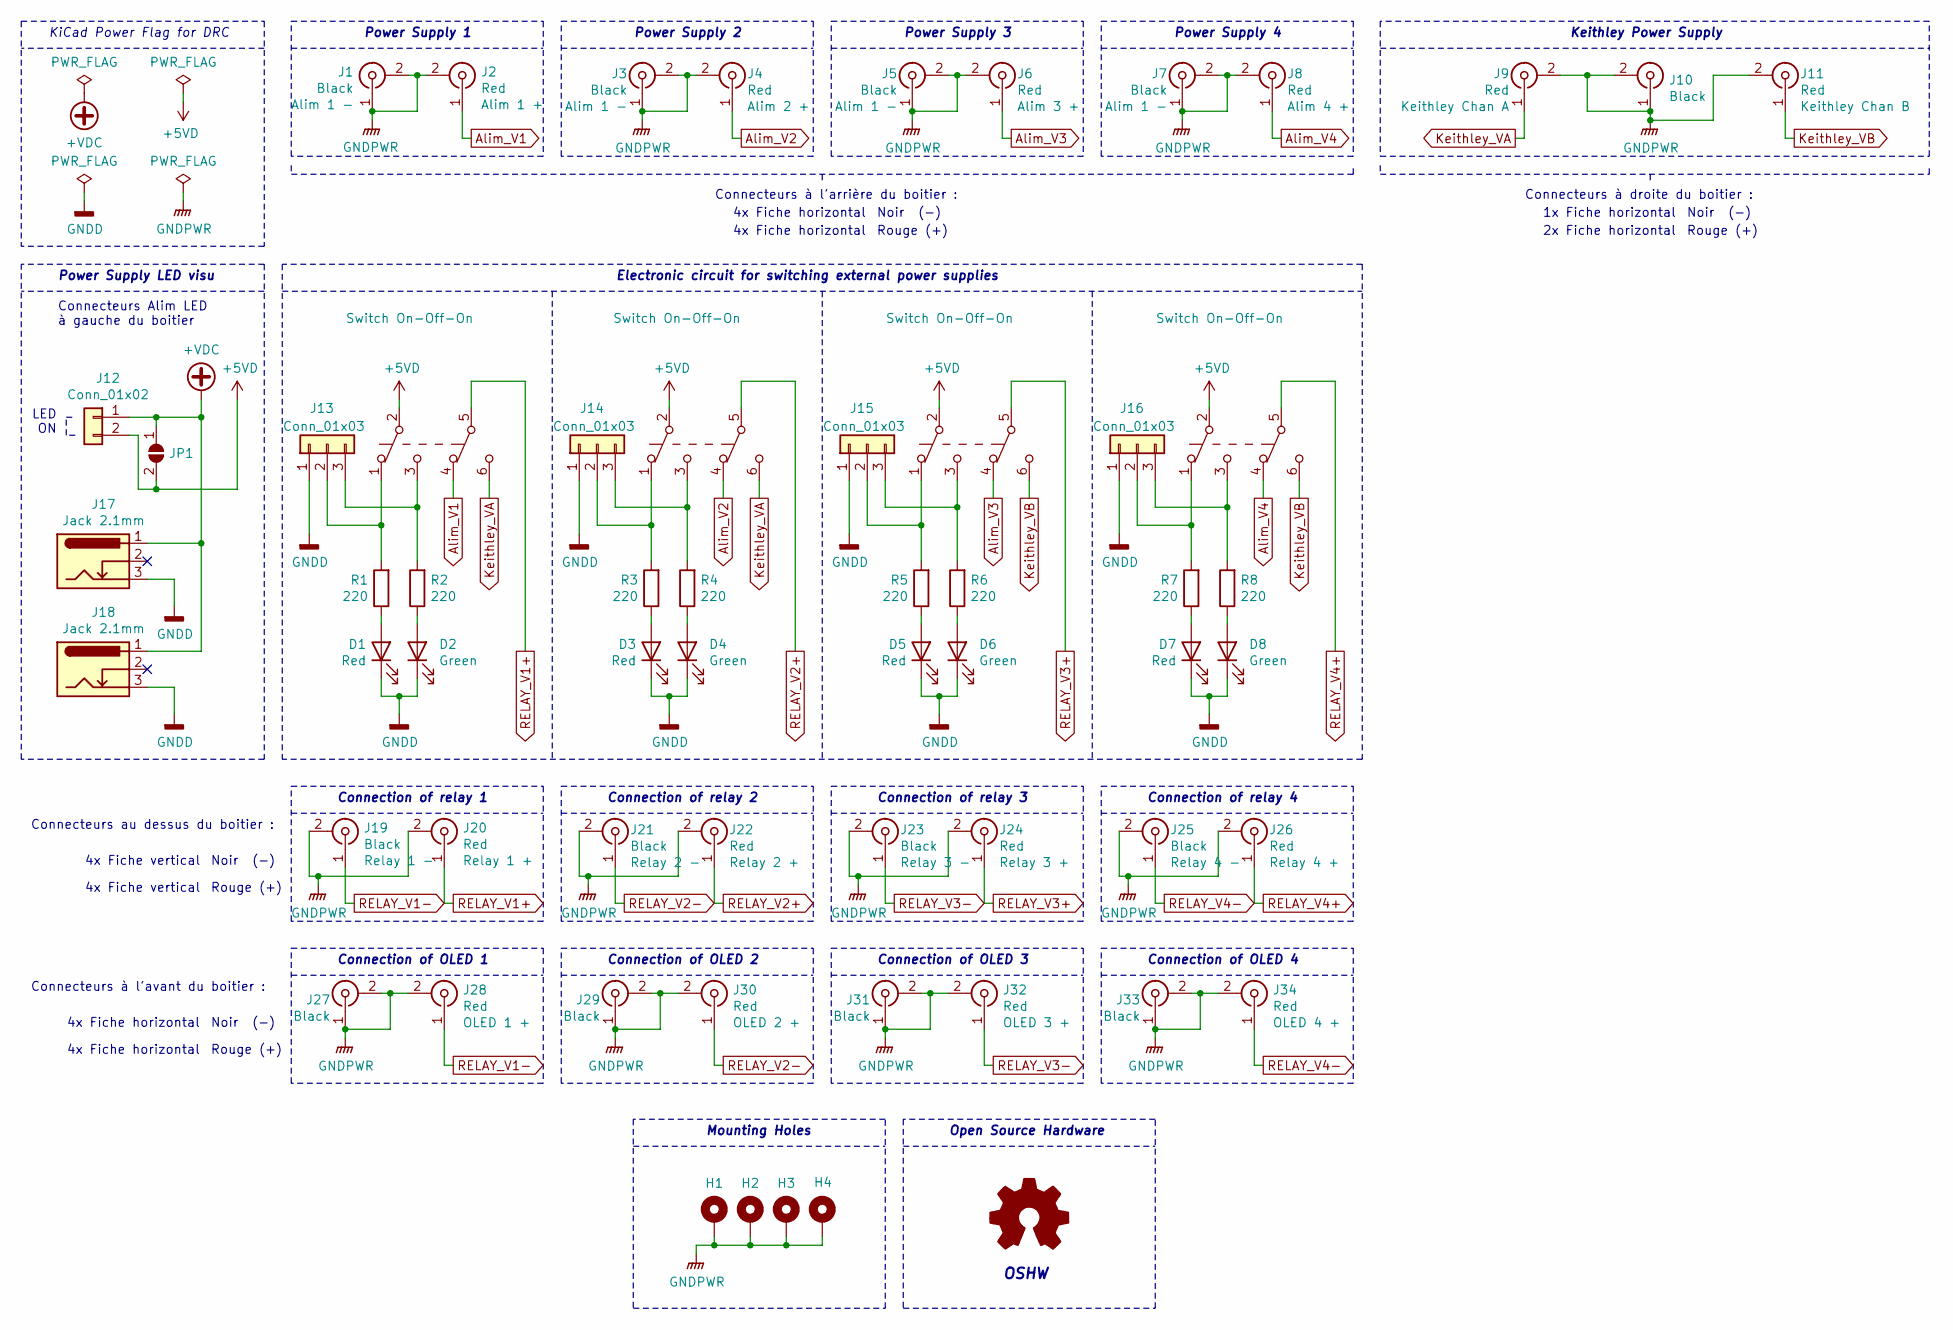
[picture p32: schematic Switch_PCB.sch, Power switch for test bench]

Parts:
D1, D3, D5, D7: Red; LED_D3.0mm_H18.0mm_Red; Manufacturer Part Number L-934ID
D2, D4, D6, D8: Green; LED_D3.0mm_H18.0mm_Green; Manufacturer Part Number L-934GD
H1, H2, H3, H4: MountingHole_Pad; MountingHole_3.2mm_M3_Pad
J1, J3, J5, J7, J10, J27, J29, J31, J33: Black; SCHUTZINGER_SWEB8094AU-SW_4mm_Horizontal_Black; Manufacturer Part Number SWEB 8094 Au / SW
J2, J4, J6, J8, J9, J11, J28, J30, J32, J34: Red; SCHUTZINGER_SWEB8094AU-RT_4mm_Horizontal_Red; Manufacturer Part Number SWEB 8094 Au / RT
J12: Conn_01x02; PinHeader_1x02_P2.54mm_Horizontal
J13, J14, J15, J16: Conn_01x03; PinHeader_1x03_P2.54mm_Vertical
J17, J18: Jack 2.1mm; BarrelJack_FC681465P_Pin3_Horizontal; Manufacturer Part Number FC681465P (DC-10LP)
J19, J21, J23, J25: Black; STAUBLI_66.9032-21_XELA-4_4mm_Vertical_Black; Manufacturer Part Number 66.9032-21
J20, J22, J24, J26: Red; STAUBLI_66.9032-22_XELA-4_4mm_Vertical_Red; Manufacturer Part Number 66.9032-22
JP1: SolderJumper_2_Open; SolderJumper-2_P1.3mm_Open_TrianglePad1.0x1.5mm
R1, R2, R3, R4, R5, R6, R7, R8: 220; R_1206_3216Metric_Pad1.30x1.75mm_HandSolder; Manufacturer Part Number CRG1206F220R
SW1, SW2, SW3, SW4: Switch On-Off-On; SW_TME_1MD3T1B1M1QE_DPDT_Straight; Manufacturer Part Number 1MD3T1B1M1QE

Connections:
+5VD: J12.2, JP1.2 (B), SW1.2 (B), SW2.2 (B), SW3.2 (B), SW4.2 (B)
+VDC: J12.1, J17.1, J18.1, JP1.1 (A)
Alim_V1: J2.1 (In), SW1.4 (A)
Alim_V2: J4.1 (In), SW2.4 (A)
Alim_V3: J6.1 (In), SW3.4 (A)
Alim_V4: J8.1 (In), SW4.4 (A)
GNDD: D1.1 (K), D2.1 (K), D3.1 (K), D4.1 (K), D5.1 (K), D6.1 (K), D7.1 (K), D8.1 (K), J13.1, J14.1, J15.1, J16.1, J17.3, J18.3
GNDPWR: H1.1, H2.1, H3.1, H4.1, J1.1 (In), J1.2 (Ext), J2.2 (Ext), J3.1 (In), J3.2 (Ext), J4.2 (Ext), J5.1 (In), J5.2 (Ext), J6.2 (Ext), J7.1 (In), J7.2 (Ext), J8.2 (Ext), J9.2 (Ext), J10.1 (In), J10.2 (Ext), J11.2 (Ext), J19.2 (Ext), J20.2 (Ext), J21.2 (Ext), J22.2 (Ext), J23.2 (Ext), J24.2 (Ext), J25.2 (Ext), J26.2 (Ext), J27.1 (In), J27.2 (Ext), J28.2 (Ext), J29.1 (In), J29.2 (Ext), J30.2 (Ext), J31.1 (In), J31.2 (Ext), J32.2 (Ext), J33.1 (In), J33.2 (Ext), J34.2 (Ext)
Keithley_VA: J9.1 (In), SW1.6 (C), SW2.6 (C)
Keithley_VB: J11.1 (In), SW3.6 (C), SW4.6 (C)
unnamed: D1.2 (A), R1.1
unnamed: D2.2 (A), R2.1
unnamed: D3.2 (A), R3.1
unnamed: D4.2 (A), R4.1
unnamed: D5.2 (A), R5.1
unnamed: D6.2 (A), R6.1
unnamed: D7.2 (A), R7.1
unnamed: D8.2 (A), R8.1
unnamed: J13.2, R1.2, SW1.1 (A)
unnamed: J13.3, R2.2, SW1.3 (C)
unnamed: J14.2, R3.2, SW2.1 (A)
unnamed: J14.3, R4.2, SW2.3 (C)
unnamed: J15.2, R5.2, SW3.1 (A)
unnamed: J15.3, R6.2, SW3.3 (C)
unnamed: J16.2, R7.2, SW4.1 (A)
unnamed: J16.3, R8.2, SW4.3 (C)
RELAY_V1+: J20.1 (In), SW1.5 (B)
RELAY_V1-: J19.1 (In), J28.1 (In)
RELAY_V2+: J22.1 (In), SW2.5 (B)
RELAY_V2-: J21.1 (In), J30.1 (In)
RELAY_V3+: J24.1 (In), SW3.5 (B)
RELAY_V3-: J23.1 (In), J32.1 (In)
RELAY_V4+: J26.1 (In), SW4.5 (B)
RELAY_V4-: J25.1 (In), J34.1 (In)

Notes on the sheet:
KiCad Power Flag for DRC
Keithley Power Supply
Power Supply 1
Power Supply 2
Power Supply 3
Power Supply 4
Connection of relay 1
Connection of relay 2
Connection of relay 3
Connection of relay 4
Connection of OLED 1
Connection of OLED 2
Connection of OLED 3
Connection of OLED 4
4x Fiche vertical
Rouge (+)
Noir (-)
Connecteurs au dessus du boitier :
Electronic circuit for switching external power supplies
Power Supply LED visu
Connecteurs à l'arrière du boitier :
4x Fiche horizontal
Connecteurs à l'avant du boitier :
Connecteurs à droite du boitier :
1x Fiche horizontal
2x Fiche horizontal
Connecteurs Alim LED à gauche du boitier
OSHW
Mounting Holes
Open Source Hardware
LED ON

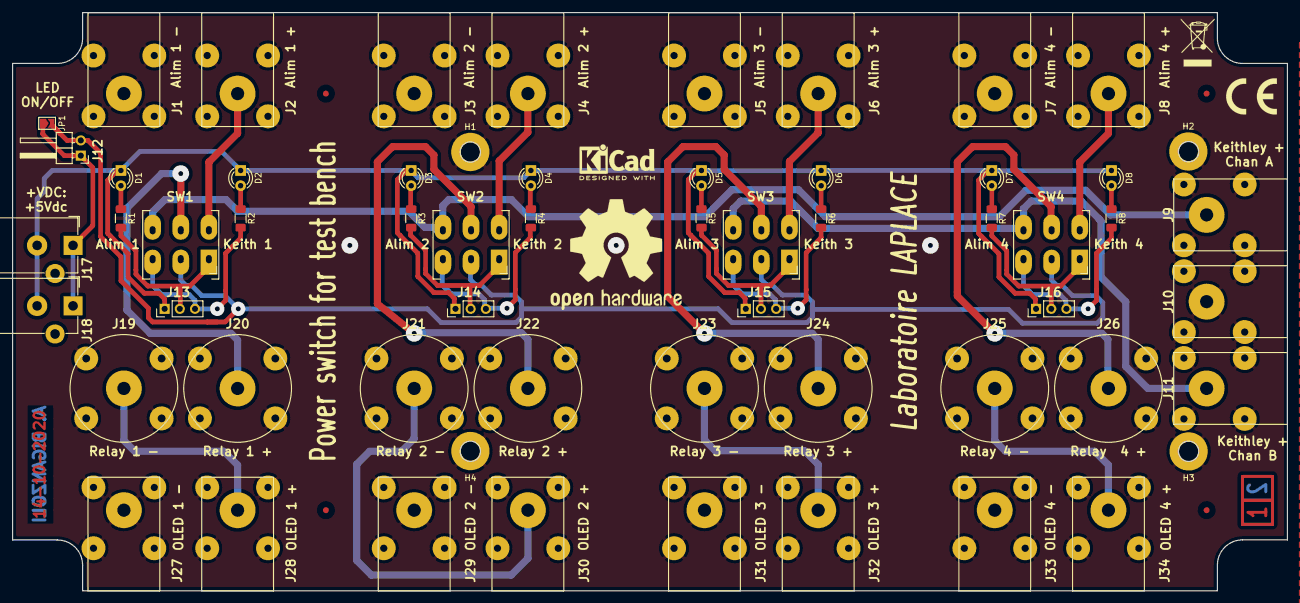
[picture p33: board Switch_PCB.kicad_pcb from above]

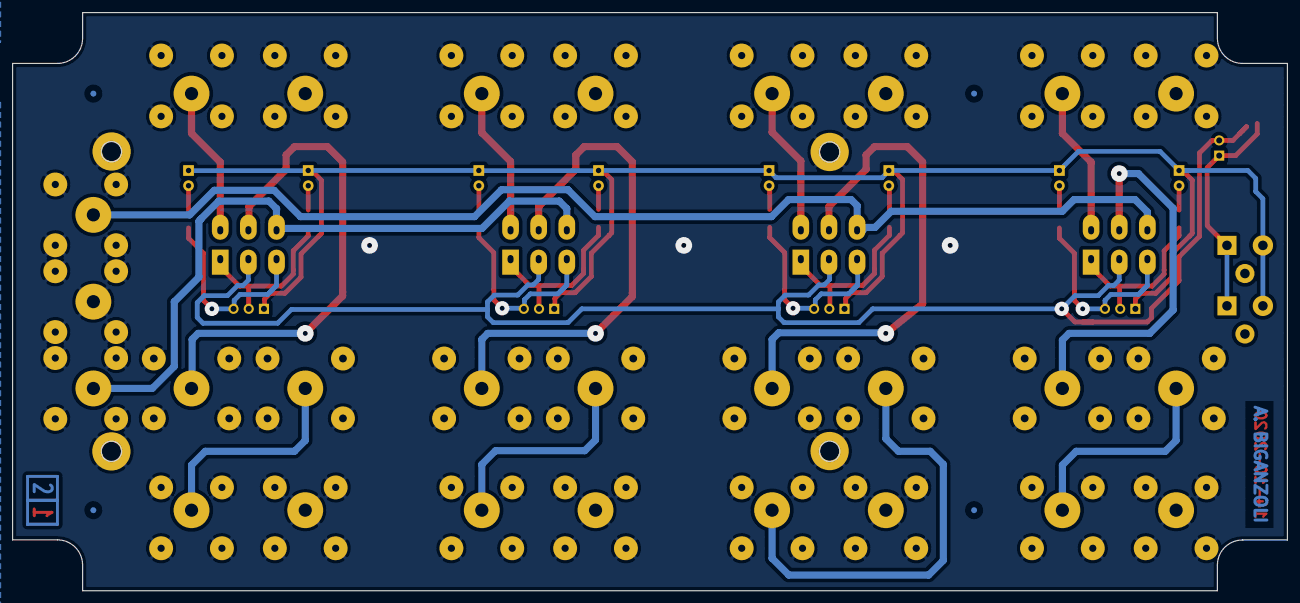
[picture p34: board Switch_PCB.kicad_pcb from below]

Board: 2 copper layers, 213.0 x 96.6 mm, 63 parts (2 on the bottom side), 34 nets.

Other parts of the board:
Ref**: L
Ref**#2, Ref**#3, Ref**#4: L

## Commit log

2020-09-24 Push the whole power switch project
    [Switch_PCB.kicad_pcb, Switch_PCB.sch, Switch_PCB_BOM.xlsx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]
2020-09-25 - validation schématique - validation du contour du PCB - validation du placement des composants, verrouillage des empreintes correctement positionnées
    [Switch_PCB.kicad_pcb, Switch_PCB.sch]
2020-09-26 Update color for each Banana connector to the pcb component placement 3d rendered.
    [Switch_PCB.kicad_pcb, Switch_PCB.sch]
2020-09-28 Update to ARNAULDDEV_SYS3DMOD global env var
    [Switch_PCB.kicad_pcb]
2020-09-28 - Add 3 pin conn for LED states - Start of the routing of the tracks of the electronic card
    [Switch_PCB.kicad_pcb, Switch_PCB.sch]
2020-09-28 Duplicate tracks
    [Switch_PCB.kicad_pcb]
2020-09-29 Screen printing validation
    [Switch_PCB.kicad_pcb]
2020-09-30 Routing completed
    [Switch_PCB.kicad_pcb]
2020-10-01 Add via to GNDPWR
    [Switch_PCB.kicad_pcb]
2020-10-02 Project review and mechanical integration
    [Hammond-1599HGYBAT.step, Switch_PCB.kicad_pcb, Switch_PCB_BOM.xlsx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]
2020-10-05 Update README files
    [Switch_PCB.kicad_pcb]
2020-10-07 Create local components library
    [Switch_PCB.kicad_pcb, Switch_PCB.sch]
2020-10-07 Update local inter footprint SW_TME_1MD3T1B1M1QE_DPDT_Straight.kicad_mod, change for oblong hole. Add packages3D in kicad_local_mod folder.
    [Switch_PCB.kicad_pcb, Switch_PCB.sch]
2020-10-09 Change 3dshapes file name from (model ${ARNAULDDEV_SYS3DMOD}/ArnauldDev_ to (model ${KIPRJMOD}/kicad_local_mod/packages3d/
    kicad_local_mod/packages3d/ArnauldDev_Button_Switch_THT.3dshapes/SW_DPDT_11.43x12.70mm_W4.83mm_P4.70mm_Straight.step
    kicad_local_mod/packages3d/ArnauldDev_Button_Switch_THT.3dshapes/SW_DPDT_11.43x12.70mm_W4.83mm_P4.70mm_Straight.wrl
    kicad_local_mod/packages3d/ArnauldDev_Connector_Banana.3dshapes/SCHUTZINGER_SWEB8094AU-SW_4mm_Horizontal_Black.step
    kicad_local_mod/packages3d/ArnauldDev_Connector_Banana.3dshapes/SCHUTZINGER_SWEB8094AU-SW_4mm_Horizontal_Red.step
    kicad_local_mod/packages3d/ArnauldDev_Connector_Banana.3dshapes/STAUBLI_66.9032-21_XELA-4_4mm_Vertical_Black.step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
    [Switch_PCB.kicad_pcb]
2020-10-09 Update path for 3D modeles to packages3d Add fiducial marks in pcb
    [Switch_PCB.kicad_pcb]
2020-10-10 Update project Add layers number
    [Switch_PCB.kicad_pcb, Switch_PCB.sch]
2020-10-11 Change the origin of SCHUTZINGER_SWEB8094AU-RT_4mm_Horizontal_Red.kicad_mod 3D model
    [SW_TME_1MD3T1B1M1QE_DPDT_Straight.FCStd, Switch_PCB.kicad_pcb]
2020-10-11 Create 3D model for green and red LED 3.0mm
    [LED_D3.0mm_H18.0mm_Green.step, LED_D3.0mm_H18.0mm_Red.step, led-3mm-green-h18mm.FCStd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]
2020-10-11 Change LED 3mm with 15.2mm Leads for 18 mm high * LED_D3.0mm_H18.0mm_Red * LED_D3.0mm_H18.0mm_Green
    [Switch_PCB.kicad_pcb, Switch_PCB.sch]
2020-10-14 Update mechanical integration
    [Switch_PCB.kicad_pcb]
2020-11-02 Ajout des trous sur la face avant (voir le PB de rotation...)
2020-11-03 New housing box
2020-11-03 Holes in the front of the housing
2020-11-03 Draw on the side of the box for the Keithley power supply
2020-11-03 Drawing eight holes on the top side of the box
